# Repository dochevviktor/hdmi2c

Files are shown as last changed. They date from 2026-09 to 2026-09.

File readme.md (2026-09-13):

# HDMI2C Monitor Controller

HDMI2C allows network control (via WiFi) of monitors connected to it via HDMI (via
[DDC]). This allows you to build your own tooling and control systems for your monitors,
rather than relying on awkward inconvient buttons and OSDs. Think of it as an API for
your monitors.

This repository contains the hardware design, made with [KiCAD]. The current
**rev2 XIAO ESP32-C6 carrier is CAD-checked but not physically tested**. Its
[prototype package](hardware/rev2/README.md) includes the BOM, schematic, assembly
drawings, a detailed [3D assembly view](hardware/rev2/assembly-3d-front.png), STEP,
Gerbers, and drills. Open the current project with KiCad 10.

The staged plan for a single-monitor board, XIAO ESP32-C6 migration, and ESPHome
firmware is in [PLAN.md](PLAN.md), including progress and handoff notes for future
sessions. The [upstream BOM and schematic][pages] describe the original revision,
not the current carrier.

## What could you build with this

- A physical brightness knob
- Switch a monitor's input when you wake up your desktop PC or connect your laptop
  to your dock
- IDK probably some other weird shit

## Features

- Seeed Studio XIAO ESP32-C6 with Wi-Fi; soldered castellated mounting
- The XIAO's USB-C power, native programming/logging, regulator, and boot/reset
- One HDMI port (`J7`, HDMI1) with:
  - TPD12S016PWR-based 3.3 V/5 V DDC translation and buffered HPD input
  - Independently controlled DDC enable and protected HDMI 5 V output
- Two small top-actuated buttons and four back-side diagnostic pads
- 42 × 24 mm two-layer carrier with antenna cutout and copper keepouts

Rev2 has 12 fitted components, including the purchased XIAO module, and a 68%
smaller bounding-box area than the 70 × 45 mm single-port rev1. Connector overhangs
are outside those dimensions. There are no mounting holes; provide enclosure
support and cable strain relief.

See the [hardware notes and pin mapping](docs/stage2-hardware.md) for design
decisions, resource provenance, verification, and outstanding physical tests.
ERC/DRC and schematic/PCB parity are clean; 20 design/BOM/preview regression tests pass.
See the [JLCPCB preparation notes](docs/jlcpcb.md) before ordering: factory-specific
settings are applied and all 12 fitted part identities are matched, but final
assembly placement and assembler approval remain pending. J7 is the exact Würth
685119134923 HDMI socket, now matched to JLCPCB **C2930961**.
Historical rev1 findings are recorded in [stage-1 validation](docs/stage1-validation.md).

The updated [review workflow](docs/automation.md) validates rev2 and generates an
interactive BOM/schematic preview using KiCad 10. Pull requests cannot deploy to
Pages. The build was tested locally, including its pinned container; GitHub-hosted
execution and deployment have not been run here.

## JLCPCB submission files

The standard handoff is a ZIP of the [fabrication folder](hardware/rev2/fabrication/)
**including Gerbers, outline and drill files**, plus the clean
[BOM](hardware/rev2/bom-jlcpcb-draft.csv) and a finalized centroid/CPL placement file.
Use the same reviewed revision for all three. The user-managed `bom.csv` is a
matching report, not the clean upload BOM.

The [draft CPL](hardware/rev2/cpl-jlcpcb-draft.csv) puts the raw
[placement CSV](hardware/rev2/positions-front.csv) into JLCPCB's column format, but
U3/J7 still use footprint origins rather than centroids and all rotations are
unverified. Correct those in the online placement preview and confirm XIAO module
handling and soldering the HDMI shell tabs before ordering. See the
[submission checklist](docs/jlcpcb.md#files-to-submit).

## Firmware

Firmware is not included yet. [Stage 3 of the plan](PLAN.md#stage-3--esphome-firmware-over-wi-fi)
will add ESPHome firmware for Wi-Fi control of brightness and input selection,
targeting the XIAO ESP32-C6 carrier from stage 2.

## A word on monitor compatibility

Not all monitors implement DDC that well. Particularly of annoyance, some models I
tested would not listen to DDC commands on inputs that were not active, which, given
this project relies on you having a spare HDMI input which never carries any video, is
kind of a deal breaker.

### Known good monitors

- Dell U2515h — reported working by the original project's author with the
  original hardware/firmware; not yet retested with this XIAO/ESPHome redesign.

## Deferred ideas (outside the current plan)

- A larger carrier option with mounting holes
- Spare ESP32 IO broken out to headers for ease of hacking
- More ambitious, HDMI passthrough to allow use of the project without taking up a whole
  spare HDMI port.

## Is it that useful tho?

You can achieve the same thing without having to build your own hardware with a
Raspberry Pi 4. Support for dual monitor I2C (DDC) was added shortly before I started
this project - guess I didn't check enough :-). This is a much more accessible means to
achieve the same goal. However, if you want a more minimal solution that doesn't require
an entire embedded linux system, this project may be for you.

[DDC]: https://en.wikipedia.org/wiki/Display_Data_Channel
[KiCAD]: https://kicad.org
[pages]: https://wlcx.github.io/hdmi2c

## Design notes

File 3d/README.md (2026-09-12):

# Local 3D models

## XIAO ESP32-C6

`Seeed_Studio_XIAO_ESP32C6.step` is the unmodified STEP supplied by the user in
`seeed-studio-xiao-esp32-c6-1.snapshot.3.zip` on 2026-09-12. It comes from the
[GrabCAD entry](https://grabcad.com/library/seeed-studio-xiao-esp32-c6-1) linked by
[Seeed's resource page](https://wiki.seeedstudio.com/xiao_esp32c6_getting_started/#resources).
The earlier HTTP 403 download limitation is resolved by this local snapshot.

- Original filename: `Seeed Studio XIAO ESP32-C6.step`.
- STEP header timestamp: 2024-11-06T17:15:41+01:00; archive entries: 2024-11-07.
- STEP AP214, millimetres; header identifies Autodesk Translation Framework.
- Assembly label: `Seeed Studio XIAO ESP32-C6 v7`. This is a **CAD model label**,
  not evidence of a hardware V7 revision. It predates the 2026 V1.0 schematic
  used for the carrier's electrical design. Verify the actual purchased module.

SHA-256:

```text
d4d2e3a05c969d69077b256c8b1567805f29be1901635768448c9dc12687c388  supplied ZIP
2e1ce01f4497192485823ca9fffd68e323bafc84cd7b85c2906b5497550be8fc  imported STEP
```

The archive includes front/back reference images but no explicit license or
author attribution file. Retain the source link and verify the applicable terms
before externally redistributing this model or derived assembly exports. The
Seeed schematic/footprint CC BY-SA notice does **not** establish this model's
license. No external publication was performed as part of this integration.

## XIAO placement in KiCad

The library footprint and U3 PCB instance both use
`${KIPRJMOD}/3d/Seeed_Studio_XIAO_ESP32C6.step`, with:

| Setting | X | Y | Z |
| --- | ---: | ---: | ---: |
| Offset, mm | 15.0014 | 8.759341 | 0.25 |
| Scale | 1 | 1 | 1 |
| Rotation, degrees | -90 | 0 | -90 |

The source axes map to footprint 3D axes as `(X,Y,Z) = (source Z, source X,
source Y)` before translation. The source board underside is at Y = -0.25 mm;
the Z offset places it at the mounting plane. It is **not a 0.25 mm standoff**.
The source body is 17.780 × 20.955 × 1.250 mm, close to the official nominal
17.8 × 21 mm outline; it is not scaled to hide this difference. All seven
castellation row centres on both sides align with the carrier's 2.54 mm pitch.
The USB points outward and the ceramic antenna lies over the open notch.

See the [mechanical review](../docs/stage2-hardware.md#detailed-3d-review) and
[rev2 assembly exports](../hardware/rev2/README.md) for clearances, limitations,
and repeatable commands. Other models in this folder predate this integration;
their existing provenance and rights are unchanged.

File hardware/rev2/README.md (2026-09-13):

# Rev2 prototype package

**CAD-checked; not built or electrically tested. Do not treat this as a qualified
production release.** Read the [hardware notes](../../docs/stage2-hardware.md)
before fabrication or assembly. No order or external publication was performed.
JLCPCB preparation is documented in [JLCPCB notes](../../docs/jlcpcb.md).
**J7 is now matched to C2930961; final placement and assembler approval remain pending.**

- [Schematic PDF](schematic.pdf)
- [Engineering BOM](bom-design.csv): 12 fitted components, including the XIAO,
  with reviewed specifications and purchasing fields.
- [JLCPCB matching CSV](bom.csv): user-managed snapshot with J7 explicitly
  corrected to C2930961. Other rows are preserved; this is not the clean upload BOM.
- [JLCPCB draft BOM](bom-jlcpcb-draft.csv) and [BOM audit](checks/jlcpcb-bom.json):
  seven matched part groups / 12 components; J7 is the existing Würth socket,
  685119134923 / C2930961. Still a draft pending assembly review, not a release.
- [Front assembly](assembly-front.svg) and [back assembly](assembly-back.svg):
  enlarged 4:1 drawings; the back view is mirrored. All fitted parts are front-side;
  the four back test pads are not fitted components.
- [1:1 fit-check PDF](fit-check-1to1.pdf): print at 100%, with page fitting disabled.
  Confirm the carrier measures 42 × 24 mm before comparing actual parts.
- [Front copper](copper-front.svg) and [back copper](copper-back.svg).
- [3D front view](assembly-3d-front.png), [3D back view](assembly-3d-back.png), and
  [assembly STEP](assembly.step): include the detailed XIAO and all 12 fitted parts.
  Nominal envelope is about 43.90 × 25.51 × 8.38 mm, excluding cables and solder.
  The supplied XIAO model is from 2024; check the actual module revision and the
  [model provenance/redistribution caveat](../../3d/README.md) before reuse.
- [Placement data](positions-front.csv): mm, absolute KiCad origin, standard
  KiCad rotations. **U3's footprint origin is not its body centroid**; the assembler
  must check its machine origin and rotation. This is not a finalized JLCPCB CPL;
  U3 and J7 require offset/rotation review. J7 is mixed SMT/plated-slot assembly
  and is included in this file, not omitted as a non-SMD part.
- [JLCPCB draft CPL](cpl-jlcpcb-draft.csv) and [CPL report](checks/jlcpcb-cpl.json):
  those 12 placements in JLCPCB's `Designator,Mid X,Mid Y,Layer,Rotation` format.
  XY and rotations are unchanged, so U3/J7 still need centroid corrections and all
  rotations need placement-preview review.
- [Fabrication files](fabrication/): two copper layers, both solder masks and
  silkscreens, paste, outline, plated/non-plated Excellon drills, and drill maps.
  There are 33 plated 0.3 mm vias and four plated 0.9 mm-wide routed HDMI shell
  slots. The separate NPTH drill file and back-paste layer are intentionally empty.
- [ERC report](checks/erc.json), [DRC/parity report](checks/drc.json),
  [netlist](checks/netlist.xml), [source hashes](checks/source-sha256.txt), and
  [nominal 3D clearance report](checks/mechanical-3d.json). The latter records
  source and STEP hashes; it is not evidence of a physical fit or RF test.

Fabrication assumptions: 2 layers, 1.6 mm FR-4, nominal 35 µm (1 oz) copper, green mask;
0.20 mm minimum tracks/clearance, 0.60/0.30 mm vias, 0.30 mm copper-to-edge
clearance, 0.12 mm mask web, and 1.0/0.15 mm minimum silk text height/stroke.
Confirm these, mask web capability, routed plated slots, and stencil
handling of the XIAO with the fabricator. The 42 × 24 mm measurement excludes
connector overhangs. There are no mounting holes; provide enclosure support.

Regenerate from the project root with KiCad 10 and its standard symbol, footprint,
and 3D-model libraries plus the `pcbnew` Python module:

```sh
bash scripts/export_rev2.sh
sha256sum -c hardware/rev2/checks/source-sha256.txt
```

The export script runs ERC, DRC/parity, the electrical/mechanical/model contract
check, and 20 regression tests before exporting production-format files. It never
overwrites `bom.csv`. Every purchasing identity/footprint mismatch stops the export;
all 12 identities now match. If the export
fails, do not use earlier output files as a release for the newly edited design.
The updated [review workflow](../../docs/automation.md) shares that validation
gate and generates a separate 2D preview; it does not publish this whole package.
Its build was tested locally in the pinned KiCad container. Actual GitHub-hosted
execution and Pages deployment have not been run here.

For JLCPCB, the normal handoff is a ZIP of `fabrication/` **including drills**,
the clean BOM, and a finalized centroid/CPL. See the [submission checklist](../../docs/jlcpcb.md#files-to-submit).
Do not submit `positions-front.csv` or the unmodified draft CPL as an approved CPL:
custom-part offsets/rotations and JLCPCB's placement preview still need review.

### Repeat the solid-clearance review

This optional audit uses OpenCascade, separately from the KiCad checks above.
After exporting, refresh its report in an isolated environment (verified here
with Python 3.14 and the pinned dependency):

```sh
cad_review_dir="$(mktemp -d -t hdmi2c-3d.XXXXXX)"
python3 -m venv "$cad_review_dir/venv"
"$cad_review_dir/venv/bin/pip" install -r scripts/requirements-3d.txt
"$cad_review_dir/venv/bin/python" scripts/check_rev2_3d.py hardware/rev2/assembly.step \
  --output hardware/rev2/checks/mechanical-3d.json
```

Reuse that environment for subsequent audits. The script checks XIAO-to-substrate
and XIAO-to-other-part solid intersections/distances, HDMI shell-to-substrate
interference, and the antenna's projection onto the carrier. It requires models
for all fitted parts and a current source manifest. It does not check solder,
cable plugs, enclosure, tolerances, or RF. Re-exporting the STEP changes its hash;
rerun this audit before citing an older report as current.

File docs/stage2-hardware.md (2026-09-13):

# Stage 2 — XIAO ESP32-C6 carrier (rev2)

Design date: 2026-09-12. This is a prototype design, not tested hardware.
See [PLAN.md](../PLAN.md) for project status and the remaining bring-up work.
The ESPHome implementation is still stage 3; no working firmware is implied.
For the current factory settings, selected purchasing codes, and unresolved
connector/assembly decisions, see [JLCPCB preparation](jlcpcb.md).

## What changed

The complete Seeed Studio XIAO ESP32-C6 replaces the bare WROOM module. Its
USB-C socket, native USB programming, regulator, RF circuit, and boot/reset
buttons replace the carrier's USB socket, CP2102N, regulator, programming
transistors, and reset circuit. There is no battery connection on this carrier.

The single HDMI connector remains `J7`, Würth **685119134923**. The old discrete
DDC level shifters, HPD divider, jumpers, and HDMI supply circuit are replaced by
`U4`, **TPD12S016PWR**, in the solderable **PW/TSSOP-24** package. This is not the
pin-compatible UQFN version. The old nominal 5 V LDO is no longer in the USB-to-HDMI
path, avoiding its input-headroom problem. Component references reused across
revisions do not imply interchangeable parts; use the rev2 BOM and schematic.

The carrier has a **42 × 24 mm bounding box**, versus 70 × 45 mm in stage 1:
68% less bounding-box area. The antenna notch removes additional material.
There are **12 fitted components**, plus four etched test pads (16 footprints).
The XIAO counts as one purchased assembly; its onboard parts are not counted
individually. Mounting holes are omitted. Two smaller, top-actuated
Omron B3U-1000P buttons replace the original forward-facing switches.

## Pin and power contract for firmware

The table uses **physical XIAO castellation numbers**, not ESP32 chip pad numbers.
KiCad's local net names acquire a leading `/` in the netlist.

| Function / net | Old WROOM GPIO | XIAO label | ESP32-C6 GPIO | U3 pad | Other endpoint |
| --- | --- | --- | --- | --- | --- |
| `I2C_SDA` | 27 | D4 | 22 | 5 | U4.3 SDA_A |
| `I2C_SCL` | 26 | D5 | 23 | 6 | U4.2 SCL_A |
| `HDMI_5V_EN`, active high | 18 | D0 | 0 | 1 | U4.12 CT_HPD |
| `DDC_EN`, active high | New | D1 | 1 | 2 | U4.5 LS_OE |
| `HDMI_HPD`, input | 16 | D2 | 2 | 3 | U4.4 HPD_A |
| `BUTTON1`, active low | 13 | D8 | 19 | 9 | SW2.1 |
| `BUTTON2`, active low | 14 | D9 | 20 | 10 | SW3.1 |
| `+3V3`, regulator output | — | 3V3 | — | 12 | U4.24 VCCA; button pull-ups |
| `GND` | — | GND | — | 13 | Common carrier/HDMI ground |
| `VBUS`, USB 5 V | — | 5V | — | 14 | U4.11 VCC5V |

Unused castellations 4, 7, 8, and 11 are intentionally unconnected. No carrier
signal uses the C6 strapping GPIOs 4, 5, 8, 9, or 15, or its native USB GPIO12/13.
The module retains its own boot/reset buttons. Mapping was checked against Seeed's
schematic/pinout and the [Espressif datasheet, v1.5](https://www.espressif.com/sites/default/files/documentation/esp32-c6_datasheet_en.pdf).

Reserve internal **GPIO3** for RF-switch enable (low) and **GPIO14** for antenna
selection (low for onboard ceramic, high for external). These are not carrier
I/O. Stage 3 must initialize them using the selected framework's XIAO support or
explicit startup configuration. See [Seeed's RF-switch instructions](https://wiki.seeedstudio.com/xiao_esp32c6_getting_started/#hardware-overview).

Suggested startup sequence for stage 3:

1. Set `HDMI_5V_EN` and `DDC_EN` low before configuring monitor control.
2. Initialize the XIAO antenna selection and Wi-Fi; configure HPD as an input.
3. Assert `HDMI_5V_EN`, then allow a conservative 10 ms initial settling interval.
   This is a proposed firmware margin, not a measured monitor-ready time.
4. Assert `DDC_EN`; start DDC at 100 kHz with open-drain signaling and bounded
   timeouts. Verify clock stretching, signal levels, and transaction timing on
   hardware before relying on communication.
5. To turn the HDMI interface off, disable DDC first, then remove HDMI 5 V.

Never intentionally leave LS_OE high with CT_HPD low: TI marks that state invalid.
HPD is advisory for this application; do not assume an inactive monitor input
must report HPD before trying DDC. Monitor readiness and retry timing need actual
monitor tests. The new `DDC_EN` output is mandatory, not interchangeable with the
old single-enable firmware wiring. R24/R25 are 100 kΩ pulldowns; R26/R27 are
10 kΩ button pull-ups. Both buttons short their signals to ground when pressed.

## HDMI electrical interface

| J7 pin | Signal | U4 PW pin / connection |
| --- | --- | --- |
| 15 | SCL, 5 V side | 8 SCL_B |
| 16 | SDA, 5 V side | 9 SDA_B |
| 17 | DDC ground | Common GND |
| 18 | Switched HDMI 5 V | 13 5V_OUT |
| 19 | HPD, 5 V side | 10 HPD_B |
| 2, 5, 8, 11, SH | Pair shields / shell | Common GND |

U4 ground pins **6, 14, and 19** all connect to ground. Unused CEC pins 1/7 and
TMDS clamp pins 15/16/17/18/20/21/22/23 are intentionally unconnected; this board
does not send video. C1/C2/C3 are 100 nF bypass capacitors on VCC5V, VCCA, and
5V_OUT respectively, with short local connections and nearby ground vias.

The [TI datasheet, SLLSE96F, October 2015](https://www.ti.com/lit/ds/symlink/tpd12s016.pdf)
specifies integrated DDC pull-ups (10 kΩ to VCCA; 1.75 kΩ to 5V_OUT), level
translation, HPD buffering, and connector-side protection. Do not fit extra DDC
pull-ups by default. The HDMI supply supports a 55 mA load; short-circuit limiting
is 150 mA typical (100–200 mA), **not a precise 55 mA cutoff**. Output drop is
50 mV maximum at 55 mA under the stated test conditions. Reverse-current blocking
is specified on 5V_OUT and the cable-side DDC/CEC pins when powered down. These
component specifications do not establish board-level ESD or HDMI certification.

USB supplies both the XIAO and HDMI load. Do not inject a second supply into
U3.14/TP1 or connect a battery for this revision. Test cable/supply voltage drop
and Wi-Fi transients. The buffered DDC interface has an A-side low-level offset;
bench-check logic-low margins and avoid cascading another offset-type bus buffer
without an electrical review. Keep the HDMI cable disconnected for initial
power-up and solder inspection.

## Mechanical and assembly review

- Two copper layers, nominal 1.6 mm FR-4. The board outline has 1 mm radii and an
  open antenna notch. Copper clearance to the outline is 0.3 mm minimum.
- U3 is soldered by its 14 side castellations, with USB at the carrier's upper
  edge. Its PCB body is nominally 21 × 17.8 mm. The USB socket projects beyond the
  carrier outline; 42 × 24 mm describes the carrier, **not the assembled envelope**.
- The local XIAO footprint preserves Seeed's side-pad coordinates, size, and
  numbering. Underside debug/test/battery lands 15–24 were deliberately removed.
  The interior beneath the module prohibits front copper, pads, and vias so
  exposed underside module contacts cannot touch carrier conductors.
- The antenna is over the notch at the opposite end from USB. A separate rule
  area prohibits copper, traces, vias, and pads on **both copper layers**. Keep
  an enclosure, metal fasteners, and cables away from this end; RF performance
  and enclosure clearance are not validated by DRC.
- The XIAO top-side boot/reset buttons and external antenna socket remain
  accessible. Side solder fillets remain reachable. Assemble the low components
  first, inspect for bridges, then fit the module/HDMI socket as appropriate to
  the assembly process. Verify a 1:1 print against actual parts before ordering.
- J7 faces the right edge. Its original SMT and plated-slot land geometry is
  retained, reviewed against the [Würth drawing, rev. 001.002](https://www.we-online.com/components/products/datasheet/685119134923.pdf).
  The body/courtyard and local STEP transform are included. Through-hole shell
  tabs require solder; an SMT-only assembly operation is insufficient.
- There are no screw holes. Provide nonconductive enclosure support and cable
  strain relief; do not treat the castellated joints as cable-load supports.
- All fitted parts are on the front. TP1–TP4 are **back-side** exposed pads:
  HDMI 5 V, GND, SCL, SDA. Back assembly plots are mirrored for a bottom view.
- The user supplied Seeed's linked GrabCAD STEP snapshot after the original
  download returned HTTP 403. It is now linked in both the local XIAO footprint
  and U3 PCB instance. Nominal 3D checks are below; physical fit is still pending.

### Detailed 3D review

Reviewed on 2026-09-12 using KiCad 10.0.6 STEP exports/renders and OpenCascade
(`cadquery-ocp 8.0.1.0.0`). All 12 fitted components have models; test pads do not
need separate models. The XIAO STEP is a **2024 mechanical snapshot**, not proof
of the exact purchased module revision. See [model provenance and transform](../3d/README.md).
The 3D integration itself changed neither electrical design, routing, lands,
outline, nor BOM. The subsequent JLCPCB follow-up updates purchasing metadata
and silkscreen, as documented separately.

| Nominal CAD check | Result |
| --- | --- |
| XIAO castellation rows | All 14 align to the footprint's seven 2.54 mm-pitch rows |
| XIAO versus other fitted parts | No solid overlap; nearest is R24 at 1.82 mm; U4 at 2.82 mm |
| XIAO / carrier substrate | No solid overlap; flat modeled underside at the mounting plane |
| HDMI shell / carrier substrate | No solid overlap; tabs pass through the plated slots |
| USB overhang beyond the carrier's upper edge | 1.512 mm; plug and strain relief not modeled |
| Ceramic antenna projection / carrier material | Over the notch; minimum planar edge distance approximately 0.294 mm |
| Overall modeled assembly envelope | Approximately 43.90 × 25.51 × 8.38 mm, including connector overhangs and shell tabs |

The small antenna-to-notch edge distance is **not an RF clearance recommendation**.
The existing all-layer copper keepout remains unchanged, but a successful geometric
check does not establish reception, detuning, or enclosure/cable clearance.
Verify Wi-Fi with physical parts and revise the keepout/notch if tests require it.

The model's Z offset corrects its source origin; it does not add a solder standoff.
The STEP export's 0.085 mm module-to-FR4 separation reflects the nominal mounting
plane versus substrate geometry, which excludes copper/mask; it is not an assembly
gap specification. Tolerances, solder, internal XIAO part interference, mating
USB/HDMI plugs, enclosure, cable loads, and RF behavior are outside this audit.
Confirm the older model against an actual XIAO before designing a close-fitting case.

[Front](../hardware/rev2/assembly-3d-front.png) and
[back](../hardware/rev2/assembly-3d-back.png) views,
[assembly STEP](../hardware/rev2/assembly.step), and the
[hashed solid-check report](../hardware/rev2/checks/mechanical-3d.json) are included.

## Resource provenance

Resources were retrieved on 2026-09-12 from the [Seeed resource list](https://wiki.seeedstudio.com/xiao_esp32c6_getting_started/#resources).

| Resource | Version / use |
| --- | --- |
| [XIAO schematic PDF](https://files.seeedstudio.com/wiki/SeeedStudio-XIAO-ESP32C6/XIAO_ESP32_C6_v1.0_SCH_260114.pdf) | V1.0, title dated 2026-01-14; power, pinout, RF, controls |
| [XIAO KiCad project](https://files.seeedstudio.com/wiki/SeeedStudio-XIAO-ESP32C6/XIAO_ESP32_C6_v1.0_SCH&PCB_260114.zip) | Archive named 260114; PCB entry dated 2025-02-11, schematic entries January 2026; layout/mechanics cross-check |
| [XIAO footprints](https://files.seeedstudio.com/wiki/XIAO-KiCad-Library/New_XIAO_Series_Footprints.zip) | `XIAO-ESP32-C6-SMD.kicad_mod`, entry dated 2026-01-05; adapted as `hdmi2c:XIAO_ESP32C6_Castellated` |
| [XIAO symbols](https://files.seeedstudio.com/wiki/XIAO-KiCad-Library/XIAO_Series_SCH_Symbols.zip) | Used as a pinout reference; local symbol describes the 14 connected castellations and power direction |
| [Pinout workbook](https://files.seeedstudio.com/wiki/SeeedStudio-XIAO-ESP32C6/res/XIAO_ESP32C6_Pinout.xlsx) | Cross-check of GPIO labels |
| [XIAO 3D model](https://grabcad.com/library/seeed-studio-xiao-esp32-c6-1) | User-supplied snapshot.3 ZIP; STEP dated 2024-11-06, imported unchanged; [hashes and placement](../3d/README.md) |
| [Omron B3U datasheet](https://omronfs.omron.com/en_US/ecb/products/pdf/en-b3u.pdf) | B3U-1000P, non-illuminated top-actuated switch |

Downloaded Seeed source hashes (SHA-256):

```text
510f3f917bcded1201ca5c63374409183457c1ef83a836988517d6802180dad7  schematic PDF
cea2ed66da575e4a1dd6c7a9acd60583ed4a9adbf6b1d2952851c1e4199c05fc  KiCad project ZIP
36f7e87db783002f20dad0fb36136c877dbc49e051293997993a988cac065698  footprint ZIP
9a423cc0683f3f6a2716a47f817556bfe0bc1a9720041712cad36902a0c25fe5  symbol ZIP
e2dae530c359e66ba704039f86cfea4bc316596fde367d992723509777746494  pinout XLSX
```

Attribution: XIAO design and source library by Seeed Studio; the source schematic
credits Linus.Liao and carries CC BY-SA 4.0. The adapted XIAO footprint preserves
that attribution and is provided under [CC BY-SA 4.0](https://creativecommons.org/licenses/by-sa/4.0/).
Adaptations cover the carrier mounting lands, fabrication graphics, courtyard,
name, description, and the linked 3D model's placement. This notice does not
relicense the linked GrabCAD STEP, unrelated original HDMI2C assets, or third-party
KiCad libraries; the STEP archive has no explicit license file.

## Physical bring-up — not performed

- [ ] Inspect part orientation, castellations, TSSOP solder bridges, and HDMI slots.
- [ ] Verify unpowered resistance between each supply rail and ground.
- [ ] With HDMI disconnected, power from a current-limited USB supply and check
  VBUS/3V3, reset-off enables, temperature, and absence of unexpected HDMI 5 V.
- [ ] Verify USB enumeration, native flashing/logging, boot/reset, and both buttons.
- [ ] Exercise enables; check HDMI 5 V under load and disabled/powered-off backfeed
  behavior with controlled equipment, without using a monitor as a fault fixture.
- [ ] Verify Wi-Fi reception with the intended antenna, USB/HDMI cables, enclosure,
  and worst-case transmit activity; check supply dips and resets.
- [ ] Check DDC idle/low levels, rise times, clock stretching, HPD, and enable order.
- [ ] Test a monitor's active and inactive HDMI inputs, sleep/wake and cable reconnect.
- [ ] Complete stage-3 firmware tests before claiming brightness/input control works.

## CAD verification and handoff

Checked with **KiCad CLI / pcbnew 10.0.6** on 2026-09-12. The schematic was redrawn
in format 20250114; the new PCB uses format 20260206. Use KiCad 10 for this revision.
This intentionally supersedes stage 1's legacy-format preservation. Existing
unrelated project preferences were preserved; minimum clearance, copper-to-edge,
and silkscreen spacing are now 0.20, 0.30, and 0.15 mm respectively after the
JLCPCB profile update. There are no
DRC exclusions. Stage 1's 7 ERC and 10 DRC errors no longer apply to this redesign.
Results use the project's configured severities. Six inherited checks remain
ignored (missing courtyard, track endpoint centered on via, tuning-profile
geometry, footprint filters, and PTH/NPTH inside courtyard); the JSON report
lists them explicitly. No rules were disabled to obtain the rev2 result.

| Check | Result |
| --- | --- |
| ERC, including warnings | 0 findings |
| DRC, all-track errors, including warnings | 0 findings |
| Unrouted connections | 0 |
| KiCad schematic/PCB parity | 0 findings |
| Independent electrical-contract / netlist comparison | 38 matching pin groups, including 24 intentional NC groups |
| XIAO footprint comparison to downloaded Seeed library | All 14 side-pad positions, sizes, and numbers match |
| PCB outline | 42 × 24 mm; approximately 915.64 mm² material area |
| Regression tests | 20 pass: 10 design, 8 BOM parser/identity, and 2 preview-output safety checks |
| XIAO model contract | Pinned STEP hash and identical reviewed transforms in library and PCB |
| Nominal 3D checks | XIAO/carrier/component clearances, antenna projection, HDMI shell/slot clearance; details above |
| Visual review | Schematic, front/back assembly and copper, plated-slot drill output, detailed front/back 3D views |
| Physical, RF, USB/programming, monitor, and ESD tests | Not performed |

The routing was assisted locally by Freerouting 2.4.1, with manual local bypass
connections and ground-return vias, followed by KiCad clearance corrections and
zone refill. KiCad DRC is the final CAD acceptance check, not the router's score.
There are 221 track segments and 33 vias. No fabrication order was placed.

The [prototype package](../hardware/rev2/README.md) contains the BOM, placements,
assembly drawings/STEP/renders, schematic PDF, Gerbers, drills, and reports.
Run `bash scripts/export_rev2.sh` after edits; it stops on failed CAD/contract tests.
The package README also gives the separate optional OpenCascade command to refresh
the solid-check report. Its source/STEP hashes identify the assembly actually checked.
`python3 -m unittest discover -s tests -v` exercises swapped SDA/SCL, a direct
5 V-to-GPIO miswire, changed land geometry, missing/weakened antenna keepouts,
and missing/rotated/vertically misplaced XIAO models.
The JLCPCB follow-up also checks minimum silk graphic width and protects against
ambiguous matching columns, missing parts, and the wrong HDMI IC auto-match.
These are design-regression checks, not circuit simulation or evidence that DDC
works on a monitor.

Next: use the 1:1 fit print and physical bring-up checklist before trusting a
prototype. Stage 3 can begin its ESPHome component/configuration work against the
pin contract above when requested, without marking the physical stage-2 milestone
complete. Compare this older XIAO model with a sample before enclosure design.

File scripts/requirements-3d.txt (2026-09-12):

# Optional solid-clearance audit; not needed for KiCad exports or electrical checks.
cadquery-ocp==8.0.1.0.0

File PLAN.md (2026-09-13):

# HDMI2C development plan

This is the handoff document for continuing work across sessions. Read it together
with `readme.md`, inspect the working tree, and update the checkboxes and session
notes after each meaningful change. Do not assume a checked design task has been
tested on physical hardware.

## Intended result

A small, inexpensive controller for one monitor, connected to a spare HDMI input
and controlled over Wi-Fi using ESPHome. Initial controls are brightness and input
selection through DDC/CI over I2C. The final MCU board is a Seeed Studio XIAO
ESP32-C6. USB supplies power; the HDMI connection does not carry video.

The stages below are sequential. Stage 1 is complete in CAD. The current
implementation request is stage 2; stage 3 is the planned firmware follow-up.
Stage 2 is now complete in CAD as `rev2`; its physical bring-up is still pending.

## Stage 1 — one HDMI port

Keep the ESP32-WROOM-32 and HDMI1 (`J7`) to isolate this change from the MCU redesign.
Keep existing reference designators so diffs and earlier assembly information
remain easy to follow.

- [x] Inspect the schematic, PCB, libraries, README, and existing local changes.
- [x] Identify the complete HDMI2 circuit to remove:
  - connector `J8`;
  - shield and I2C jumpers `JP2`, `JP7`, `JP8`;
  - level shifters `Q4`, `Q6` and pull-ups `R8`, `R10`, `R12`, `R14`;
  - HPD divider `R20`, `R21`;
  - switchable 5 V supply `U5`, `Q8`, `C6`.
- [x] Capture baseline ERC/DRC results before editing.
- [x] Remove these symbols, their wires, labels, junctions, and cached instances.
  Mark the four freed MCU pins intentionally unconnected.
- [x] Remove matching footprints, HDMI2 nets, traces, and obsolete shared-supply
  branches from the PCB. Preserve the complete HDMI1 circuit.
- [x] Reduce the board outline, reposition affected mounting holes/artwork, and
  refill copper. Record the resulting dimensions and component-count reduction.
- [x] Verify schematic/PCB connectivity, ERC, DRC, and visual exports. Record
  inherited findings separately from regressions; resolve new electrical or
  mechanical errors introduced by this change.
- [x] Update README and record a stage-1 handoff here. Generated manufacturing
  files should only be treated as release files after the outstanding checks pass.

Acceptance: exactly one HDMI connector in schematic and PCB, no HDMI2 circuitry
or routing, HDMI1 pin connectivity preserved, a smaller board, and explicit
verification results. A physical build is a separate validation milestone.

## Stage 2 — XIAO ESP32-C6 carrier

- [x] Read Seeed's schematic, pinout, dimensions, and CAD resources; record the
  exact module revision and resource versions used. The documented module size
  is 21 × 17.8 mm. This is a carrier redesign, not a pin-compatible WROOM swap.
- [x] Add/verify a local symbol and footprint for the complete XIAO board,
  including pad numbering, mounting method, USB clearance, antenna clearance,
  and access to boot/reset. Prefer soldered castellated pads for compactness;
  check assembly access before fixing the layout.
- [x] Create an explicit old-to-new signal mapping. Start with XIAO `D4/GPIO22`
  for SDA and `D5/GPIO23` for SCL; select remaining exposed GPIOs for HDMI 5 V
  enable, HPD input, and any retained buttons after checking boot constraints.
  Reserve the board's antenna-control GPIOs according to Seeed's documentation.
- [x] Use the XIAO's USB-C power/programming connection and onboard regulation.
  Remove the redundant WROOM, USB connector, USB-UART bridge, auto-programming
  circuit, and associated parts once their replacement paths are confirmed.
- [x] Review the HDMI electrical interface: 3.3 V/5 V level shifting, pull-ups,
  HPD divider, common ground/shield, ESD, enable defaults, and backfeed behavior.
  Audit the inherited 5 V LDO/pass-FET circuit with USB input voltage and dropout
  in mind before deciding to retain or replace it. Do not wire 5 V DDC directly
  to an ESP32 GPIO.
- [x] Redraw and compact the carrier PCB around one HDMI connector and the XIAO.
  Revisit buttons and mounting holes only as needed for the smaller layout.
- [x] Run ERC, DRC, schematic/PCB parity, and a datasheet/2D footprint/connector
  review. Generate a BOM, assembly view, schematic PDF, Gerbers, and drills for
  the reviewed revision.
- [x] Integrate the user-supplied detailed XIAO STEP model; align it in the library
  and PCB, review nominal solid clearances, and export assembly STEP/front/back
  views. Record model provenance, transform, and repeatable checks.
- [ ] Verify the 1:1 land print against physical samples and assembled/enclosure
  clearances. Compare the 2024 model snapshot with the actual purchased module;
  cable plugs, solder, tolerances, and RF behavior remain unverified.
- [x] Review the supplied JLCPCB template and matching BOM; apply appropriate
  KiCad 10 factory limits, update silk, preserve the raw matching CSV, and save
  reviewed purchasing fields with a guarded draft export.
- [x] Update the review workflow for KiCad 10, share local/CI validation, retain
  the interactive BOM preview, and prevent pull-request Pages deployments.
  Verify the build locally in its pinned container; no remote run/publication.
- [x] Confirm J7's exact catalog identity: Würth 685119134923 / C2930961; update
  purchasing fields/BOM without a footprint substitution. All 12 identities match.
- [ ] Complete JLCPCB assembly preparation: confirm current availability, complete
  XIAO reflow/handling and HDMI shell-tab soldering, choose service/tooling/panel
  needs, and verify the final CPL offsets/rotations and placement preview.
- [ ] Bring up hardware: check USB, 3.3 V and HDMI 5 V rails, boot/programming,
  Wi-Fi reception, DDC idle levels and waveforms, and HPD/enable behavior.

Acceptance: documented XIAO pin mapping, compact carrier, resolved release-blocking
CAD findings, successful power/programming/Wi-Fi bring-up, and an electrically
verified DDC connection. Record any checks that require a physical board.

## Stage 3 — ESPHome firmware over Wi-Fi

- [ ] Review the three reference projects below at recorded commits; inspect
  their actual DDC implementations and licenses before reusing code. MoniBee
  uses the ESP32-C6 with Zigbee and is a protocol reference, not the requested
  Wi-Fi/ESPHome implementation. Distinguish DDC/CI on HDMI SDA/SCL from CEC.
- [ ] Pin a supported ESPHome version and compile a minimal XIAO configuration
  using `variant: esp32c6` and the ESP-IDF framework. Confirm flash size, USB
  logging, antenna configuration, Wi-Fi, encrypted native API, and OTA. Keep
  credentials in an untracked `secrets.yaml` with a checked-in example.
- [ ] Implement a reusable local ESPHome external component for DDC/CI. Plan
  for a configurable I2C bus/address, checksums, response validation, explicit
  transaction timing, serialized requests, bounded retries, and offline recovery.
  Verify address notation (7-bit address versus shifted wire address) against
  the source implementations. Avoid an always-running I2C scan on the DDC bus.
- [ ] Add a brightness `number` entity and input-source `select` entity. Support
  monitor-specific source codes; confirm readback and brightness scaling against
  the monitor's reported range. Identify unsupported controls without blocking
  Wi-Fi/API operation. Add power control later if supported and useful.
- [ ] Add hardware pin substitutions, conservative polling, availability/error
  reporting, safe startup behavior, and optional button actions. Keep the bus
  state machine nonblocking so network and watchdog tasks continue to run.
- [ ] Verify framing/checksum/error handling with meaningful protocol tests and
  captured/known transactions; run ESPHome config validation and compilation.
- [ ] Test on a real monitor with DDC/CI enabled: brightness set/read, input
  switch/read, inactive spare HDMI input, cable reconnect, monitor sleep/wake,
  power loss, controller reboot, Wi-Fi loss/recovery, and OTA.
- [ ] Document flashing, ESPHome/Home Assistant setup, supported monitor models
  and settings, troubleshooting, and the exact tested hardware/firmware versions.

Acceptance: an ESPHome build for this board exposing working brightness and input
controls over Wi-Fi, with readback/error handling and recorded monitor tests.

## Constraints and decisions to carry forward

- Some monitors ignore DDC on inactive inputs. Test the actual target monitor
  early; firmware cannot guarantee support on an arbitrary spare HDMI port.
- Keep the monitor's normal video connection separate. HDMI passthrough, dual
  monitors on one carrier, Zigbee/Matter, and ambient-light/IR features are outside
  the current scope.
- Stage 1 kept the existing power architecture and GPIO mapping. Stage 2 replaces
  these with the XIAO and TPD12S016PWR; use the new firmware pin contract in
  [stage-2 hardware notes](docs/stage2-hardware.md), including the new DDC enable.
- Preserve user changes. At the start of this work, `hdmi2c.kicad_pro` already had
  KiCad version/settings changes, and `.history/` and `.idea/` were untracked.
- Stage 1 retained schematic 20211123 / PCB 20211014. The stage-2 redraw uses
  schematic 20250114 / PCB 20260206, verified with KiCad 10.0.6. Use KiCad 10 for
  the new carrier. The rev1 files remain available in Git history.

## References

Reviewed for planning on 2026-09-12; recheck versions before implementing firmware.

- [Seeed XIAO ESP32-C6 pinout and resources](https://wiki.seeedstudio.com/xiao_esp32c6_getting_started/#resources)
  — module dimensions, GPIO mapping, power and antenna controls.
- [fluxfur/ddcBrightness](https://github.com/fluxfur/ddcBrightness)
  — existing HDMI monitor-control implementation to inspect for DDC behavior.
- [TeaRex-coder/hardwareddc firmware](https://github.com/TeaRex-coder/hardwareddc/tree/main/firmware)
  — ESP32 firmware; its [README](https://github.com/TeaRex-coder/hardwareddc)
  describes control through a spare HDMI input and links the DDC/VCP library.
- [ItsEcholot/MoniBee](https://github.com/ItsEcholot/MoniBee)
  — ESP32-C6 monitor control; inspect source rather than relying on its mixed
  CEC/DDC terminology. Its board is a C6 Supermini, not the XIAO.
- [ESPHome ESP32 platform](https://esphome.io/components/esp32/)
  — C6 variant and ESP-IDF support.
- [ESPHome external components](https://esphome.io/components/external_components/)
  — component integration approach to check during stage 3.

## Session handoff

### 2026-09-12 — plan and stage 1

Status: stage 1 complete in CAD; hardware validation remains outstanding.

- No firmware existed in this repository at the start of this work.
- Board outline reduced from 95 × 45 mm to 70 × 45 mm (26.3% less area). Removed
  15 circuit components; 46 PCB footprints remain including holes and artwork.
- HDMI1 (`J7`) is preserved, including its original GPIO26 SCL, GPIO27 SDA,
  GPIO16 HPD, and GPIO18 5 V enable mapping. Removed HDMI2 from both CAD files.
- Updated the local logo footprint and its PCB instance to fit the smaller board
  and identify it as `rev1`. The user-edited project settings were left intact.
- Verification: 88 matching pin groups, no unrouted connections, and no new ERC,
  DRC, or schematic/PCB parity findings compared with the baseline. Inherited
  findings remain (7 ERC errors and 10 DRC errors); this is not a fabrication
  release. See [stage-1 verification](docs/stage1-validation.md) for counts,
  retained pin mapping, limitations, and commands.
- Added `scripts/check_connectivity.py` for repeatable schematic/PCB pin-group
  comparison and optional comparison with an earlier netlist.
- Next implementation task: stage 2, starting with the official XIAO schematic,
  mechanical footprint, and explicit pin/power mapping. Review the inherited
  HDMI supply circuit and CAD findings as part of that redesign. Do not begin
  the ESPHome implementation with the old WROOM pin mapping.

### 2026-09-12 — stage 2 XIAO carrier

Status: **CAD complete; physical stage-2 acceptance not yet achieved.** Stage 3
firmware remains unimplemented. Baseline at this session's start: `af1aed1`.

- U3 is the complete XIAO ESP32-C6 V1.0, using Seeed's January 2026 schematic and
  reviewed 14 castellation lands. Resource links, hashes, and attribution are in
  [stage-2 hardware notes](docs/stage2-hardware.md).
- Replaced the WROOM support circuits and discrete HDMI interface with a
  USB-powered XIAO plus TPD12S016PWR. DDC remains properly level translated;
  CT_HPD and LS_OE have independent GPIOs and reset-off pulldowns. HDMI shell and
  signal grounds are now directly common. No external battery supply is used.
- Board is 42 × 24 mm (68% smaller bounding-box area than stage 1), with antenna
  cutout and copper keepouts. 12 fitted components / 16 footprints, including
  two smaller top-actuated buttons and four back-side test pads. No screw holes.
- Pin contract: GPIO22 SDA, GPIO23 SCL, GPIO0 HDMI 5 V enable, GPIO1 DDC enable,
  GPIO2 HPD, GPIO19/20 buttons. Reserve GPIO3/14 for the XIAO antenna controls.
  Enable HDMI 5 V before DDC; disable DDC before removing HDMI 5 V.
- Verification: 0 ERC, 0 DRC, 0 unrouted, 0 parity findings; 38 matching pin
  groups; all 14 lands compared against Seeed; six regression tests pass.
  No exclusions were introduced. All CAD issues inherited from rev1 are gone.
- Generated [rev2 prototype package](hardware/rev2/README.md), including BOM,
  assembly views, 1:1 fit print, schematic PDF, Gerbers, drills, and reports.
  Reproduce with `bash scripts/export_rev2.sh`; it gates exports on checks/tests.
- Unrelated user changes in `.history` were preserved. Existing upstream Pages
  automation was not upgraded or run. No order, push, or commit was made.
- Next physical action: verify actual parts against the fit print, then perform
  the power/USB/RF/DDC bring-up checklist. Detailed XIAO 3D fit remains pending.
  Next software action, when requested: start stage 3 against the rev2 pin contract,
  review reference project commits/licenses, then pin and compile ESPHome/C6.

### 2026-09-12 — detailed XIAO 3D model follow-up

Status: **nominal 3D review complete; physical stage-2 acceptance still pending.**
Baseline: `59bcef6`. The user supplied the previously inaccessible GrabCAD ZIP.

- Imported its STEP unchanged as `3d/Seeed_Studio_XIAO_ESP32C6.step` and linked it
  with the same transform in the local footprint and U3 PCB instance. Source
  dates, hashes, coordinate alignment, and licensing caveat are in
  [3d/README.md](3d/README.md). It is a 2024 model, not confirmation of the exact
  2026 schematic/purchased board revision; its `v7` label is not a hardware revision.
- All 14 castellation rows align. No nominal solid interference between the
  XIAO and carrier/other fitted parts; nearest component R24 is 1.82 mm away.
  HDMI shell tabs also clear the carrier substrate through their slots.
- Antenna projection is over the notch, with approximately 0.294 mm minimum
  planar distance to carrier material. This small margin is geometric only;
  physical Wi-Fi/enclosure/cable testing remains mandatory, not a CAD pass.
- Assembly model envelope is approximately 43.90 × 25.51 × 8.38 mm, including
  connector overhangs and shell tabs, excluding solder/cables. Added front/back
  renders, assembly STEP, and a hashed [solid-check report](hardware/rev2/checks/mechanical-3d.json).
- No schematic, land geometry, routing, board-outline, or BOM changes. U3 still
  counts as one purchased assembly; there are 12 fitted components.
- Verification: 0 ERC/DRC/parity/unrouted findings, 38 matching pin groups, and
  nine regression tests pass, including missing/rotated/misplaced model cases.
  `scripts/export_rev2.sh` now exports the 3D assets and hashes the local models.
  A separate optional OpenCascade audit refreshes the solid-check report; see
  [package instructions](hardware/rev2/README.md#repeat-the-solid-clearance-review).
- Unrelated `.history` changes were preserved. No commit, push, publication,
  fabrication order, physical test, or stage-3 firmware implementation was done.
- Next physical action: compare an actual XIAO/HDMI socket with the 1:1 print and
  model, check mating plugs/enclosure support, then run the power/USB/RF/DDC
  checklist. Next software action, when requested: stage 3 against the rev2 pins.

### 2026-09-12 — JLCPCB template and BOM preparation

Status: **CAD profile checked; JLCPCB assembly release blocked by sourcing and
placement/assembler approval.** Baseline `26b2222`; the user's `bom.csv` and
unrelated `.history` changes were already present and were preserved.

- Extracted the supplied template ZIP and inspected `JLCPCB_1-2Layer`. It is a
  2019 KiCad 5 snapshot that unexpectedly enables four copper layers. Kept the
  actual two-layer, 1.6 mm carrier and existing 0.20 mm track/clearance rules.
  Compared relevant limits with JLCPCB's current primary documentation. Applied
  the conservative 1 oz/green-mask profile in [JLCPCB notes](docs/jlcpcb.md).
- Strengthened via/ring/hole, mask and silk settings; enlarged/repositioned silk
  text and increased 33 silk graphics to 0.15 mm. No pad, route, via, footprint
  placement, board outline, or electrical-connectivity changes.
- Saved the six suitable user-selected MPN/LCSC groups (11 fitted parts) in the
  schematic and PCB. **J7's C516617 / PI3HDMI1310-AZLEX match is an IC, not the
  Würth 685119134923 connector.** It was not adopted. The existing connector is
  retained pending the user's sourcing/replacement choice.
- `bom.csv` stays byte-identical to the user's matching export. Regeneration now
  writes `bom-design.csv` and `bom-jlcpcb-draft.csv`; J7 stays in the draft with
  its correct MPN and blank LCSC code. The purchasing report remains blocked,
  and strict checking exits nonzero. Duplicate headers, ranged references, and
  multiline CSV fields are handled without silently choosing the wrong column.
- Verification: 0 ERC/DRC/parity/unrouted findings; 38 matching pin groups;
  16 regression tests pass (10 design, 6 BOM). Nominal 3D clearances unchanged;
  refreshed prototype outputs and source hashes. The solid-check report was
  still stale at this handoff and was corrected on 2026-09-13 below. No rule
  severity reductions, DRC exclusions, order, upload, reservation, commit, or push.
- Next action: resolve whether to source/consign the Würth connector, hand-fit it,
  or investigate a JLCPCB-stocked replacement (requires footprint review before
  adoption). Confirm XIAO reflow/handling, mixed SMT/slot soldering, service and
  tooling with JLCPCB. Economic's published size minimum accommodates 42 × 24 mm;
  Standard would require a panel/tooling solution. This is not an assembler approval.
- `positions-front.csv` remains raw KiCad data: custom U3/J7 origins need CPL
  offset/rotation verification and a placement-preview review before ordering.
  Physical fit/RF/power/DDC tests and stage-3 firmware remain unperformed.

### 2026-09-13 — JLCPCB verification and review workflow

Status: **CAD/preview checks pass; assembly sourcing and physical acceptance remain
pending.** Baseline `f5ea02e` contains the preceding JLCPCB preparation. Only the
unrelated `.history` changes were present at this session's start and were preserved.

- Confirmed all current source hashes and the byte-identical user `bom.csv`.
  The nominal solid report still referenced the pre-JLCPCB export; reran the
  pinned OpenCascade audit against the current STEP. All clearances are unchanged
  and the report now records the current STEP/PCB/manifest hashes. No CAD geometry,
  component choices or routing changes were made in this session.
- Replaced the attached workflow's KiCad 6 generator and obsolete Actions with
  the official KiCad 10.0.5 container and InteractiveHtmlBom 2.12.0. Dependencies
  are pinned by digest/commit. The official 10.0.6 image was not yet available.
  Both the local 10.0.6 build and exact 10.0.5 container build pass.
- Added a shared `validate_rev2.sh` gate used by the full prototype exporter and
  the new 2D review-site builder. It preserves the user matching CSV and permits
  only the known J7 exception for a draft. The site excludes the raw CSV, full
  fabrication package, placements and 3D assets; it labels the J7/assembly blockers.
- Pull requests produce review artifacts only; only `main` can upload/deploy
  Pages. Checkout credentials are not persisted, build permissions are read-only,
  and deploy permissions are isolated. Existing output directories are rejected
  to avoid overwriting user files or publishing stale assets.
- Verification: 0 ERC/DRC/parity/unrouted findings, 38 matching pin groups, and
  **18 passing tests** (10 design, 6 purchasing, 2 preview safety), including in
  the pinned container with a read-only project mount and no network. Inspected
  the interactive BOM in Firefox: 7 groups / 12 parts, correct J7 socket MPN with
  blank LCSC code, four test pads excluded. Index links, actionlint, ShellCheck,
  shell syntax and whitespace checks pass. Strict BOM checking still exits 1.
- Reproduction, dependencies and CI limitations are in [automation notes](docs/automation.md).
  No commit, push, GitHub run, artifact upload, Pages deployment, reservation,
  fabrication order, physical test or firmware implementation was performed.
- Next action still requires the J7 sourcing decision: retain the Würth socket
  for sourcing/consignment/hand-fitting, or authorize investigation of a stocked
  replacement and its footprint. Final CPL/assembler approval and physical tests
  remain outstanding. The owner can review/commit/push the workflow and verify
  GitHub Pages configuration separately; a green review is not assembly approval.

### 2026-09-13 — exact J7 catalog match and submission checklist

Status: **all 12 fitted part identities matched; final CPL and assembly-process
approval remain pending.** Baseline `9723b97`; unrelated `.history` changes preserved.

- The user supplied C2930961. Verified JLCPCB and LCSC identify it as the exact
  Würth 685119134923 already used by J7. Rechecked the manufacturer's land pattern:
  19 signal lands, 0.50 mm pitch, 0.28 × 2.60 mm pads and 14.50 mm shell-column
  spacing. Added only the hidden LCSC field in schematic/PCB; no footprint, slot,
  routing, outline, model or pin-mapping change.
- Corrected only J7's matching-CSV row on that selection. Cleared the old IC's
  pricing, stock/MOQ and account quantities; retained the user's quantity five.
  All other rows remain byte-identical. The original row is recoverable in Git
  history; export scripts still never overwrite the matching input. New CSV SHA-256:
  `41d7cd4179fb72cbd5afe507a82e5c78174dc66418836862444c5367fa45a1ee`.
- Updated the reviewed purchasing contract and removed the J7 export exception.
  Strict checking accepts all 12 current identities and still rejects the saved
  old IC snapshot. Added tests for accepting C2930961 and rejecting that code
  with a different footprint. The clean draft BOM now has seven fully matched
  groups; `ready_for_order` remains false because placement/process checks are separate.
- Regenerated the prototype package, source hashes and nominal 3D audit. All
  solid clearances remain unchanged. Full export and native/pinned-container
  preview builds pass: 0 ERC/DRC/parity/unrouted findings, 38 matching pin groups,
  and **20 tests** (10 design, 8 purchasing, 2 preview safety). No check exclusions.
- Updated README, package notes and the review site to distinguish matched parts
  from assembly approval. Recorded the normal three-file-set handoff in
  [JLCPCB submission notes](docs/jlcpcb.md#files-to-submit): fabrication ZIP
  including drills/outline, clean BOM, and finalized centroid/CPL from one revision.
- Next action: prepare/review the final JLCPCB CPL (column names plus U3/J7
  offsets/rotations), inspect the placement preview, and confirm complete-XIAO
  reflow/handling, four HDMI shell-tab solder joints, service/tooling and stock.
  `positions-front.csv` is still raw KiCad data, not an approved CPL. Physical
  bring-up and firmware remain separate pending stages. No order, upload,
  reservation, commit, push, GitHub deployment or physical test was performed.

### 2026-09-13 — JLCPCB draft CPL

Status: **JLCPCB-format draft CPL generated; U3/J7 centroid corrections, rotation
review and assembler approval remain pending.** Baseline `8b7c0f0` plus the user's
uncommitted CPL exporter, its tests and `export_rev2.sh` hook; `.history` preserved.

- Reviewed `scripts/export_jlcpcb_cpl.py` and `tests/test_jlcpcb_cpl.py` without
  changing them. The header, column order and `mm` values match JLCPCB's sample
  CPL; `Top`/`Bottom` is an accepted layer form and rotations stay counter-clockwise.
- Generated `hardware/rev2/cpl-jlcpcb-draft.csv` and `checks/jlcpcb-cpl.json` from
  the placement file and draft BOM, which match fresh KiCad 10.0.6 regenerations.
  All 12 designators match the BOM; XY and rotations are copied unchanged.
- JLCPCB defines Mid X/Mid Y as centroids. pcbnew shows only U3 and J7 differ from
  their pad centres (+8.917/+10.500 mm and +3.450/0 mm), so the unmodified draft
  would misplace them. Details are in the [JLCPCB notes](docs/jlcpcb.md).
- Verification: `validate_rev2.sh` passes locally, including ERC/DRC and 30 tests
  (10 design, 8 purchasing, 10 CPL, 2 preview safety). The pinned container build
  was not rerun.
- Next action: correct U3/J7 and check every rotation in JLCPCB's placement preview,
  then continue the assembly checklist. No order, upload, commit or push was made.

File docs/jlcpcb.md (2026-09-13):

# JLCPCB preparation — rev2

Factory/part review 2026-09-12; J7 confirmation and verification 2026-09-13.
**CAD checks pass; the assembly order is not ready.**
All 12 fitted component identities are now matched. Assembler acceptance,
current availability, and the final placement file still require confirmation.
No files were uploaded, no parts reserved, and no order placed.

## Template and board settings

The carrier really is **two copper layers**, 42 × 24 mm, nominal 1.6 mm FR-4.
The user-supplied `kicad_templates-master.zip` was extracted and its
`JLCPCB_1-2Layer` directory reviewed. This is a **KiCad 5 / 2019** snapshot,
archive commit `7a393457f57f22cc15bf484340ad554363761557`. Despite its name, both
its PCB and `.pro` file enable **four** copper layers (`CopperLayerCount=4`).
Its layer table, worksheet, legacy plot options, and whole project file were
therefore not imported into the working KiCad 10 design.

Archive SHA-256:

```text
9e39d52f667d11d42a962d5fce8701ad84b1f88ab81b73f83aa69e36a29d241f
```

The applied profile assumes **1 oz copper and green solder mask**. Other colors,
copper weights, finishes, or processes need a fresh review. These are local CAD
settings, not options already selected in a JLCPCB order.

| Setting, mm unless stated | Supplied template | Applied rev2 profile |
| --- | ---: | ---: |
| Copper layers | 4 (inconsistent with folder name) | 2, retained |
| Board thickness | 1.6002 | 1.6, retained |
| Minimum track / copper clearance | 0.127 / 0.127 | 0.20 / 0.20, retained |
| Minimum via diameter / drill | 0.60 / 0.30 | 0.60 / 0.30 |
| Minimum via annular width | Implicit 0.15 for default via | 0.15 |
| Minimum hole-to-hole clearance | 0.40 | 0.45, conservatively applied to all holes |
| Minimum hole-to-copper clearance | Not explicit | 0.28, conservatively applied globally |
| Copper-to-routed-edge clearance | Not explicit | 0.30, retained |
| Mask expansion / minimum web | 0 / 0.12 | 0 / 0.12 |
| Mask opening to neighboring copper | Not explicit | 0.09 |
| Minimum silkscreen text height / stroke | Defaults 0.8128 / 0.1524 | Constraints 1.0 / 0.15 |
| Silkscreen clearance | Not explicit | 0.15 |

Compared with JLCPCB's [current fabrication capabilities](https://jlcpcb.com/capabilities/pcb-capabilities):
the retained track/via choices have margin; current mask guidance permits 1:1
openings. Component PTH rings have a different requirement from via rings: the
HDMI shell lands were retained, not reduced to the via minimum. The antenna notch
and plated slots are routed features; this is not a V-scored panel.

Updated routing presets are 0.20/0.40/0.60/1.00 mm tracks and 0.60/0.30,
0.90/0.40 mm vias. Blind/buried vias and microvias remain disabled. Solder paste
expansion remains zero; vias remain tented, not specified as epoxy-filled.

The tighter checks initially found 38 silkscreen text/spacing issues. Enlarged
text, moved U4/SW2/SW3/TP references, and increased 33 footprint silkscreen
graphic strokes from 0.12 to 0.15 mm. The latter are PCB-instance styling changes;
refreshing standard footprints can reset them, so a regression check now guards
their minimum width. **Pads, traces, vias, component locations, outline, and
electrical connectivity were not changed.** No DRC exclusions or severity
reductions were used. Existing unrelated project preferences were preserved.

## Part selections

The user's [matching CSV](../hardware/rev2/bom.csv) is preserved except for the
explicit J7 correction below, based on the user's new selection on 2026-09-13.
Its duplicate `JLCPCB Part #` headers contain an empty input column and a populated
selected-part column; it also contains multiline descriptions and ranged
designators. It is a matching report, **not the clean upload BOM**.

| References | Manufacturer part / selected code | Review |
| --- | --- | --- |
| U3 | Seeed 113991254 / [C27675191](https://jlcpcb.com/partdetail/Seeed-113991254/C27675191) | Complete XIAO ESP32-C6; module handling/reflow and placement still need JLCPCB confirmation |
| U4 | TI TPD12S016PWR / [C201665](https://jlcpcb.com/partdetail/TexasInstruments-TPD12S016PWR/C201665) | Correct PW/TSSOP-24 part, not RKT/UQFN |
| SW2, SW3 | Omron B3U-1000P / [C231329](https://jlcpcb.com/partdetail/OmronElectronics-B3U1000P/C231329) | Matches the existing switch |
| R24, R25 | FOJAN FRH0603B1003TS / [C51048211](https://jlcpcb.com/partdetail/FOJAN-FRH0603B1003TS/C51048211) | 100 kΩ, 0.1 W, ±0.1%, 0603; meets design requirements |
| R26, R27 | Sunway SC0603F1002F2BNRH / [C3152123](https://jlcpcb.com/partdetail/Sunway-SC0603F1002F2BNRH/C3152123) | 10 kΩ, 0.1 W, ±1%, 0603; meets requirements |
| C1–C3 | YAGEO CC0603KRX7R9BB104 / [C14663](https://jlcpcb.com/partdetail/YAGEO-CC0603KRX7R9BB104/C14663) | 100 nF, 50 V, X7R, ±10%, 0603; exceeds the minimum 16 V requirement |
| J7 | Würth 685119134923 / [C2930961](https://jlcpcb.com/partdetail/WurthElektronik-685119134923/C2930961) | Exact existing HDMI Type A socket; no footprint substitution |

The passive-component warnings compare engineering values such as `100k` with
MPN strings. Those warnings do not by themselves indicate an electrical mismatch;
the actual selected specifications above were reviewed. Manufacturer/MPN/LCSC
fields for all seven groups (12 components) are saved in the schematic
and PCB. Stock, price, quoted order quantities, and setup fees are not pinned or
guaranteed by this review; the CSV's commercial data is only the user's snapshot.

J7 is the [Würth 685119134923 HDMI receptacle](https://www.we-online.com/components/products/datasheet/685119134923.pdf).
The user's **C2930961** selection was confirmed against the JLCPCB listing above
and [LCSC's catalog](https://www.lcsc.com/product-detail/C2930961.html), both of
which identify this exact manufacturer part. The manufacturer's land pattern
matches the existing 19 pads at 0.50 mm pitch, 0.28 × 2.60 mm signal lands, and
14.50 mm shell-tab column spacing. No pad, slot, outline, route or 3D-model change
is required. Its catalog listing specifies Economic/Standard SMT assembly, but
the four plated-slot shell tabs still need explicit soldering-process confirmation.

The original auto-match, PI3HDMI1310-AZLEX / C516617, was a switching IC and remains
rejected. Only J7's row was manually corrected in the matching CSV. Its obsolete
IC pricing, stock/MOQ and account-quantity fields were cleared, not transferred
to the socket; the user's requested quantity of five was retained. Other rows
remain byte-identical. Export/validation scripts still never rewrite this input.

## Files and export safety

- `hardware/rev2/bom.csv`: user-managed JLCPCB matching snapshot, never overwritten
  by the export script.
- [bom-design.csv](../hardware/rev2/bom-design.csv): generated engineering BOM with
  specifications and purchasing fields; 12 fitted parts.
- [bom-jlcpcb-draft.csv](../hardware/rev2/bom-jlcpcb-draft.csv): clean, uniquely
  headed **draft** using MPNs as comments, expanded references, and quantities per
  board. All seven groups / 12 components have reviewed codes, including J7
  `685119134923` / `C2930961`. It remains a draft until assembly review is complete.
- [BOM audit](../hardware/rev2/checks/jlcpcb-bom.json): records source hashes and
  all 12 reviewed identities. `unresolved_references` is empty, but
  `ready_for_order` remains false until the separate assembly checks are complete.
- [cpl-jlcpcb-draft.csv](../hardware/rev2/cpl-jlcpcb-draft.csv): generated from
  `positions-front.csv` and checked against the draft BOM's 12 designators. Its
  header, column order and `mm` values follow JLCPCB's sample CPL; XY and rotations
  are copied unchanged. The [CPL report](../hardware/rev2/checks/jlcpcb-cpl.json)
  records input hashes and keeps `ready_for_order` false.

The column format follows JLCPCB's [KiCad export guide](https://jlcpcb.com/help/article/how-to-generate-the-bom-and-centroid-file-from-kicad)
and [placement-file guide](https://jlcpcb.com/help/article/pick-place-file-for-pcb-assembly).
`positions-front.csv` remains **raw KiCad placement data**, and the draft CPL is only
a column/unit conversion, not an approved JLCPCB CPL. JLCPCB defines Mid X/Mid Y as
the component centroid, but the U3 and J7 footprint origins are not centroids:

| Ref | Draft CPL XY, mm | Pad-area centre, mm | Difference, mm |
| --- | --- | --- | --- |
| U3 | 52.000, -71.037 | 60.917, -60.537 | +8.917, +10.500 |
| J7 | 82.500, -62.000 | 85.950, -62.000 | +3.450, 0 (courtyard centre +4.375, 0) |

The other ten footprint origins coincide with their pad and courtyard centres.
Before an order, correct U3/J7 against JLCPCB's part models and verify every
rotation in the placement preview, including pin 1, USB direction, and HDMI direction.

```sh
bash scripts/export_rev2.sh
sha256sum -c hardware/rev2/checks/source-sha256.txt
# Strict purchasing-identity check: now exits 0; this is not assembly approval.
python3 scripts/check_jlcpcb_bom.py hardware/rev2/bom.csv hardware/rev2/checks/netlist.xml \
  --report hardware/rev2/checks/jlcpcb-bom.json
```

Every purchasing identity/footprint mismatch now stops the main export; the old
J7 exception has been removed. Update purchasing fields and the reviewed part contract
together after approving a new selection. Re-export and refresh the separate
solid-check report as described in the [package README](../hardware/rev2/README.md).

## Files to submit

Yes: the normal JLCPCB handoff is **one fabrication ZIP plus a BOM and a CPL**.
Keep all three synchronized to the same reviewed design revision.

| Upload | Contents / current project file |
| --- | --- |
| Fabrication ZIP | ZIP the contents of `hardware/rev2/fabrication/`: copper, solder mask, silkscreen, paste, outline **and `.drl` drill files**. Keep the antenna cutout and HDMI plated-slot routing; drill-map PDFs and `.gbrjob` are supplementary. |
| BOM | Use the clean `hardware/rev2/bom-jlcpcb-draft.csv` for matching/review, not the duplicate-header `bom.csv` matching report. It now includes C2930961 and all 12 fitted parts; finalize the order only after assembly signoff. |
| Centroid / CPL / pick-and-place | Finalize from `hardware/rev2/cpl-jlcpcb-draft.csv` (`Designator,Mid X,Mid Y,Layer,Rotation`, mm), generated from `positions-front.csv`. Apply the U3/J7 centroid corrections and verify all rotations first; the draft is **not the finalized upload CPL**. |

This follows JLCPCB's [Gerber/drill guide](https://jlcpcb.com/help/article/how-to-generate-gerber-and-drill-files-in-kicad-9)
and [BOM/CPL guide](https://jlcpcb.com/help/article/how-to-generate-the-bom-and-centroid-file-from-kicad).
J7 is mixed SMT/plated-slot, so keep it in the placement list even though KiCad
marks the footprint through-hole. TP1–TP4 are etched test pads, not purchased parts.
No schematic or STEP upload is normally part of these three required file sets;
an assembly drawing or process note can support the XIAO/HDMI handling review.

File upload alone is not the final approval: select/confirm the two-layer 1.6 mm,
1 oz/green-mask board options and assembly service, check the Gerber preview and
part matches, and inspect placement orientation before paying. In particular,
verify USB direction, HDMI direction and pin 1, and agree on XIAO reflow handling
and soldering all four HDMI shell tabs. No files were submitted by this work.

## Assembly decisions still required

JLCPCB currently lists **10 × 10 mm minimum for Economic PCBA**, versus
**70 × 70 mm for Standard PCBA**; single-sided SMT/through-hole assembly is listed
for Economic. Thus this 42 × 24 mm carrier meets Economic's size requirement, but
that alone does not establish acceptance of these parts. Standard would require
a suitable larger panel/tooling arrangement. Their [assembly capabilities](https://jlcpcb.com/capabilities/pcb-assembly-capabilities)
also distinguish tooling/fiducial requirements by service.

- [x] Resolve J7's exact catalog identity: Würth 685119134923 / C2930961.
- [ ] Confirm current J7 availability and explicitly include soldering its four
  plated-slot shell tabs, not just its SMT contacts.
- [ ] Have JLCPCB confirm placement and the soldering profile for the **complete
  XIAO module**; a catalog listing is not approval of this custom carrier mounting.
- [ ] Confirm Economic versus Standard, actual component availability, finish,
  stencil, handling of the notched outline/overhanging connectors, and any panel,
  rails, fiducials, or tooling holes. Do not enlarge the carrier just to match the
  Standard minimum without choosing that process first.
- [x] Convert placements to JLCPCB's CPL columns: `cpl-jlcpcb-draft.csv`.
- [ ] Correct U3/J7 centroids, verify all rotations, and inspect JLCPCB's placement
  preview before paying.
- [ ] Perform the existing physical fit, power, USB, RF, and monitor checks.

The carrier itself has no castellated edge holes: the castellations belong to
the purchased XIAO. Do not select special carrier edge-plating/castellation
fabrication solely because the module uses castellated mounting.

Validation: KiCad 10.0.6 ERC/DRC/parity/unrouted **0 findings**, 38 matching pin
groups, and **20 regression tests pass** (10 design, 8 BOM, 2 preview safety).
The [review workflow](automation.md) also passes the same checks in its pinned
KiCad 10.0.5 container. Nominal 3D clearances are unchanged and the separate
solid report now matches the current STEP/source hashes. This is CAD/purchasing
preparation, not JLCPCB DFM/DFA approval or a physical test.

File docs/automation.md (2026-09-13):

# Rev2 review automation

Updated 2026-09-13. The [workflow](../.github/workflows/main.yml) builds a **CAD
review preview**, not an approved fabrication/assembly package. A green run does
not resolve the [JLCPCB placement and assembly checks](jlcpcb.md).

## What runs

Pushes to `main`, pull requests targeting `main`, and manual workflow runs:

1. Use the official KiCad **10.0.5** container, pinned by digest, and
   InteractiveHtmlBom **2.12.0**, pinned by commit. The official registry did not
   yet have 10.0.6; local CAD work uses 10.0.6. Both were tested below.
2. Run `scripts/validate_rev2.sh`: ERC, DRC/parity/unrouted checks, the 38-group
   electrical contract, footprint/model/keepout/silk checks, and 20 regression
   tests (10 design, 8 purchasing, 2 preview-output safety tests).
3. Audit the matching CSV without changing it. All 12 fitted part identities
   must match; the former J7 exception is removed after confirming C2930961.
4. Generate an interactive BOM, schematic PDF, engineering BOM, clearly named
   JLCPCB draft BOM, and reports into a **new** `out/` directory. J7 retains its
   correct socket MPN with C2930961. Test pads do not count as fitted parts.
5. Retain diagnostics even after a failed check. Upload a review preview only
   after a successful build. Upload/deploy Pages **only from `main`, never from a
   pull request**. A manual run on another branch produces a preview only.

The build token has read-only repository permissions and checkout credentials
are not persisted. Only the separate deploy job has Pages/OIDC write permissions.
Pull-request builds can cancel superseded PR builds; Pages deployments are serialized.
No workflow was dispatched, pushed, or deployed during this local work. Actual
GitHub-hosted execution and the repository's Pages/environment settings remain to
be verified by the owner after committing/pushing the changes.

## What is deliberately excluded

The site does not copy `hardware/rev2/` wholesale. It excludes the raw user matching
CSV, Gerbers, raw placements/CPL, STEP files and 3D renders. The supplied model's
[redistribution caveat](../3d/README.md) is unchanged. CI neither refreshes nor
claims to run the optional OpenCascade solid audit; it only checks the pinned
local model and its CAD transform as part of the regular design contract.

The full prototype exporter still uses `scripts/export_rev2.sh`. Its validation
gate is now shared with CI, and it still never overwrites `hardware/rev2/bom.csv`.
The [separate solid audit](../hardware/rev2/README.md#repeat-the-solid-clearance-review)
must be rerun after exporting new STEP geometry. A review site is not a substitute
for that package or for physical hardware tests.

## Local preview

With KiCad 10, its standard symbol/footprint libraries and `pcbnew` Python module
installed, run from the project root:

```sh
preview_dir="$(mktemp -d -t hdmi2c-preview.XXXXXX)"
git clone --no-checkout https://github.com/openscopeproject/InteractiveHtmlBom.git \
  "$preview_dir/InteractiveHtmlBom"
git -C "$preview_dir/InteractiveHtmlBom" checkout --detach \
  5c192e794cd66fde04bab11810601b711bf8581b
bash scripts/build_review_site.sh "$preview_dir/InteractiveHtmlBom" "$preview_dir/site"
# Open the generated site/index.html in a browser.
```

The builder refuses an existing output directory rather than deleting it or
mixing in stale assets. Choose a new path on each run. An export failure may leave
partial diagnostics there, but CI will not upload it as a successful site.
To run checks without building a site:

```sh
validation_dir="$(mktemp -d -t hdmi2c-checks.XXXXXX)"
bash scripts/validate_rev2.sh "$validation_dir"
```

## Verification and dependency provenance

- Complete headless preview builds passed locally on KiCad 10.0.6 and in the
  **exact pinned 10.0.5 container**, with a read-only project mount and networking
  disabled for the container build. Both returned zero ERC/DRC/parity/unrouted
  findings, 38 matching pin groups, and 20 passing tests.
- Inspected the generated interactive BOM in Firefox: 7 groups / 12 fitted parts,
  four test pads excluded, correct J7 socket MPN and C2930961 purchasing code.
  All review-index links resolve. Strict identity checking exits 0; the old
  incorrect IC snapshot still fails. Assembly approval remains separate.
- `actionlint` 1.7.12, ShellCheck, shell syntax and whitespace checks pass. These
  local checks do not test GitHub authentication, artifact uploads or deployment.
- The matching CSV's J7 row was explicitly corrected on the user's selection of
  C2930961; all other rows are unchanged. Export scripts never rewrite it.
  The current digest is recorded in `hardware/rev2/checks/source-sha256.txt`.

The removed upstream generator [installs KiCad 6](https://github.com/wlcx/kicad-site-generator/blob/main/Dockerfile).
The replacement uses [KiCad's official container distribution](https://www.kicad.org/download/docker/)
and [InteractiveHtmlBom 2.12.0](https://github.com/openscopeproject/InteractiveHtmlBom/releases/tag/v2.12.0).
Official actions are pinned to verified release commits: [checkout 7.0.1](https://github.com/actions/checkout/releases/tag/v7.0.1),
[upload-artifact 7.0.1](https://github.com/actions/upload-artifact/releases/tag/v7.0.1),
[upload-pages-artifact 5.0.0](https://github.com/actions/upload-pages-artifact/releases/tag/v5.0.0),
and [deploy-pages 5.0.1](https://github.com/actions/deploy-pages/releases/tag/v5.0.1).
Dependency updates require a new preview build and review; none floats on `main`.

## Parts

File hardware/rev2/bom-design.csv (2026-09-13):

References | Value | Footprint | Quantity | Manufacturer | MPN | LCSC Part # | Specification | Datasheet
C1-C3 | 100nF | Capacitor_SMD:C_0603_1608Metric | 3 | YAGEO | CC0603KRX7R9BB104 | C14663 | 100 nF; >=16 V; X7R; +/-10%; 0603
J7 | HDMI1 | hdmi2c:WURTH_685119134923_HDMI | 1 | Wurth Elektronik | 685119134923 | C2930961 | HDMI Type A receptacle; SMT contacts and plated-slot shell tabs | https://www.we-online.com/components/products/datasheet/685119134923.pdf
R24,R25 | 100k | Resistor_SMD:R_0603_1608Metric | 2 | FOJAN | FRH0603B1003TS | C51048211 | 100 kohm; >=0.1 W; +/-1%; 0603
R26,R27 | 10k | Resistor_SMD:R_0603_1608Metric | 2 | Sunway | SC0603F1002F2BNRH | C3152123 | 10 kohm; >=0.1 W; +/-1%; 0603
SW2,SW3 | B3U-1000P | Button_Switch_SMD:SW_SPST_B3U-1000P | 2 | Omron | B3U-1000P | C231329 | Top-actuated SPST-NO; no locating boss | https://omronfs.omron.com/en_US/ecb/products/pdf/en-b3u.pdf
U3 | XIAO ESP32-C6 | hdmi2c:XIAO_ESP32C6_Castellated | 1 | Seeed Studio | 113991254 | C27675191 | Complete V1.0 module; 14 soldered castellations; 4 MB flash | https://files.seeedstudio.com/wiki/SeeedStudio-XIAO-ESP32C6/XIAO_ESP32_C6_v1.0_SCH_260114.pdf
U4 | TPD12S016PWR | Package_SO:TSSOP-24_4.4x7.8mm_P0.65mm | 1 | Texas Instruments | TPD12S016PWR | C201665 | PW/TSSOP-24; do not substitute the RKT pinout | https://www.ti.com/lit/ds/symlink/tpd12s016.pdf

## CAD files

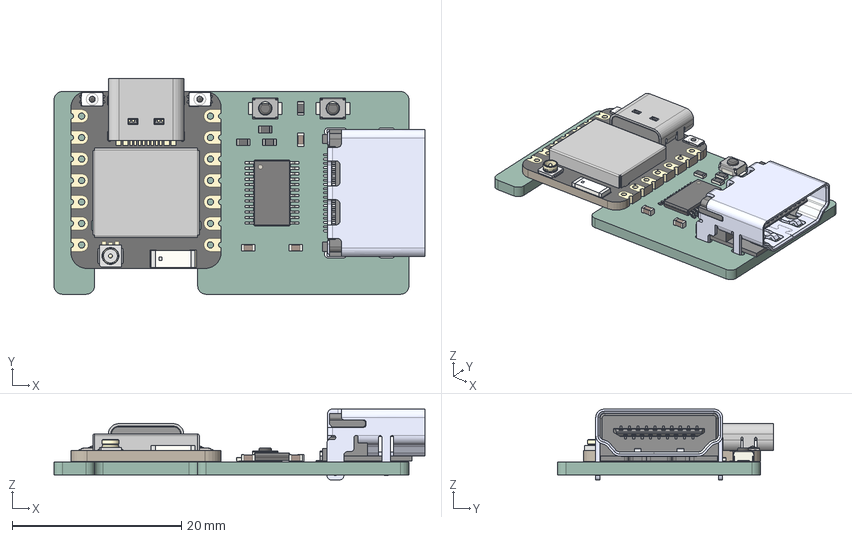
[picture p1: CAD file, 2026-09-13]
hardware/rev2/assembly.step
43.9 x 25.5 x 8.38 mm
SW_SPST_B3U-1000P x 2
R_0603_1608Metric x 4
TSSOP-24_4.4x7.8mm_P0.65mm
BOSS-EXTRUDE14_8_
BOSS-EXTRUDE7_4_
BOSS-EXTRUDE7_3_
BOSS-EXTRUDE14_4_
BOSS-EXTRUDE14_2_
BOSS-EXTRUDE14_11_
BOSS-EXTRUDE7_7_
BOSS-EXTRUDE14_9_
BOSS-EXTRUDE14_3_
BOSS-EXTRUDE14_7_
MIRROR2
BOSS-EXTRUDE14_5_
BOSS-EXTRUDE14_12_
BOSS-EXTRUDE7_8_
BOSS-EXTRUDE7_1_
BOSS-EXTRUDE14_10_
BOSS-EXTRUDE7_9_
BOSS-EXTRUDE14_6_
BOSS-EXTRUDE14_1_
BOSS-EXTRUDE7_6_
BOSS-EXTRUDE7_2_
CUT-EXTRUDE5
BOSS-EXTRUDE7_5_
U.FL Connector v1
Shield
SKTAAAE010 v1 x 2
KH5220-A36 (Ceramic Antenna) v2
C_0603_1608Metric x 3
hdmi2c_PCB

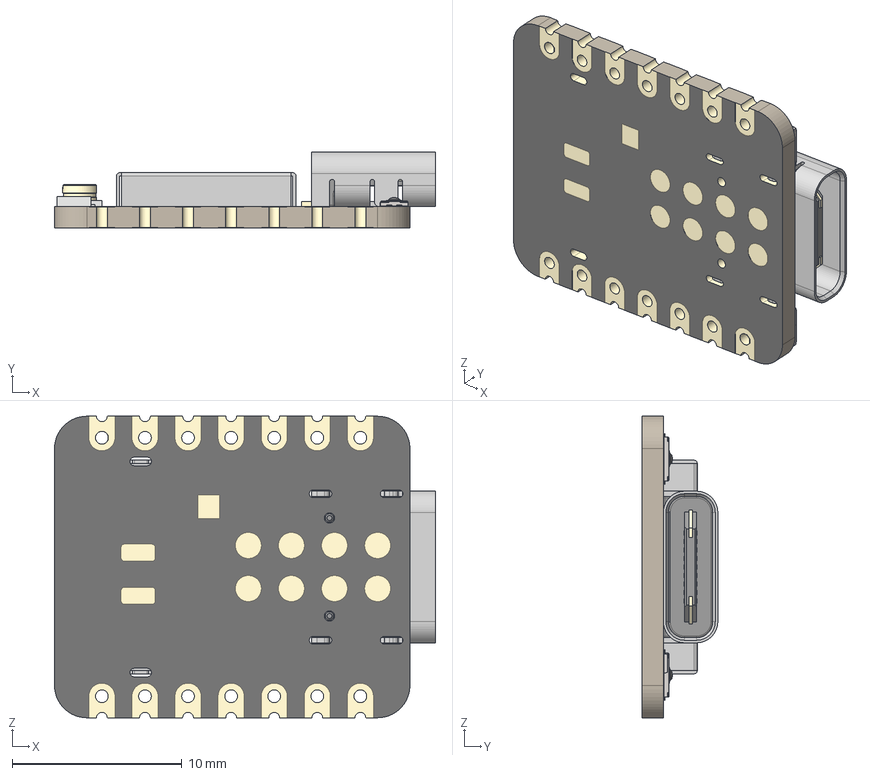
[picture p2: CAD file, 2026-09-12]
3d/Seeed_Studio_XIAO_ESP32C6.step
22.5 x 4.46 x 17.8 mm
BOSS-EXTRUDE14_8_
BOSS-EXTRUDE7_4_
BOSS-EXTRUDE7_3_
BOSS-EXTRUDE14_4_
BOSS-EXTRUDE14_2_
BOSS-EXTRUDE14_11_
BOSS-EXTRUDE7_7_
BOSS-EXTRUDE14_9_
BOSS-EXTRUDE14_3_
BOSS-EXTRUDE14_7_
MIRROR2
BOSS-EXTRUDE14_5_
BOSS-EXTRUDE14_12_
BOSS-EXTRUDE7_8_
BOSS-EXTRUDE7_1_
BOSS-EXTRUDE14_10_
BOSS-EXTRUDE7_9_
BOSS-EXTRUDE14_6_
BOSS-EXTRUDE14_1_
BOSS-EXTRUDE7_6_
BOSS-EXTRUDE7_2_
CUT-EXTRUDE5
BOSS-EXTRUDE7_5_
U.FL Connector v1
Shield
SKTAAAE010 x 2
KH5220-A36 (Ceramic Antenna) v2

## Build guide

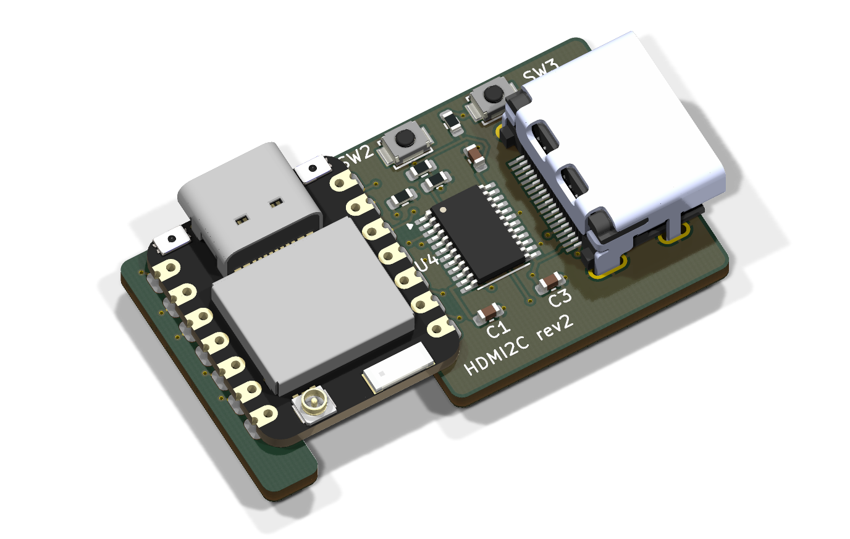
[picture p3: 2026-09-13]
hardware/rev2/assembly-3d-front.png

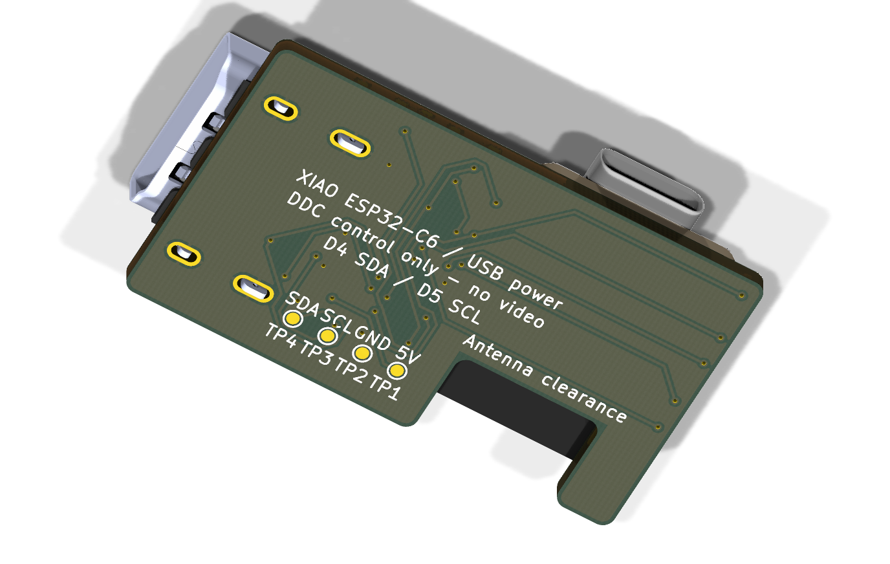
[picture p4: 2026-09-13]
hardware/rev2/assembly-3d-back.png

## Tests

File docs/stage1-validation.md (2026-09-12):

# Single-HDMI hardware revision

Revision: `rev1`, 2026-09-12. Stage 1 is complete in CAD. This is an intermediate
ESP32-WROOM-32 design; the XIAO carrier and ESPHome firmware are still planned.
The board has not been built or tested on a monitor, and the inherited findings
below must be reviewed before fabrication.

## Changes

- Kept HDMI1 (`J7`) and its complete DDC level shifting, HPD divider, shield jumper,
  switchable 5 V supply, and I2C jumpers.
- Removed `J8`, `JP2`, `JP7`, `JP8`, `Q4`, `Q6`, `Q8`, `R8`, `R10`, `R12`,
  `R14`, `R20`, `R21`, `U5`, and `C6` from schematic and PCB, together with their
  nets and routing. Removed dedicated branches of the shared power/ground nets.
- Marked U3 pins 8, 9, 28, and 31 (GPIO32, GPIO33, GPIO17, GPIO19) as intentionally
  unconnected. Their old HDMI2/I2C2 signal labels and traces are gone.
- Reduced the outline from 95 × 45 mm to 70 × 45 mm: 4,275 to 3,150 mm², a 26.3%
  area reduction. Moved the two right mounting holes 25 mm left while preserving
  the corner radius and hole-to-edge spacing.
- Moved the copper logo above the MCU, scaled it to 80%, and updated its revision
  glyph to `rev1`. Updated the local footprint library to match. The original
  creator's name and 2021 artwork attribution remain.
- Refilled the bottom ground plane. Kept the original schematic format 20211123
  and PCB format 20211014, without a wholesale KiCad format conversion.
- Reduced the populated circuit from 56 to 41 component footprints. Total PCB
  footprints went from 61 to 46, including four mounting holes and one logo.

## Retained pin mapping

This table is for the stage-1 WROOM design. Stage 2 will define the XIAO mapping.

| Function | ESP32-WROOM-32 | HDMI connector / path |
| --- | --- | --- |
| DDC SCL | GPIO26, U3 pin 11 | JP3 → Q3 → J7 pin 15 |
| DDC SDA | GPIO27, U3 pin 12 | JP4 → Q5 → J7 pin 16 |
| HPD sense | GPIO16, U3 pin 27 | J7 pin 19 → R18/R19 divider |
| HDMI 5 V enable | GPIO18, U3 pin 30 | U4 enable → Q7 → J7 pin 18 |
| DDC ground | GND | J7 pin 17 |

## Verification results

Compared against the original schematic/PCB at commit
`3f064aa6c761e88b313b9f9e71b1f0dff42e0744`, using the user's existing project
settings and KiCad CLI 10.0.6. The existing `hdmi2c.kicad_pro` changes were preserved
byte-for-byte. Both baseline and revised DRC runs refilled zones.

| Check | Original | Stage 1 |
| --- | ---: | ---: |
| HDMI connectors | 2 | 1 |
| Unrouted connections (DRC) | 0 | 0 |
| ERC errors | 12 | 7 |
| ERC warnings | 351 | 257 |
| DRC errors | 18 | 10 |
| DRC warnings | 58 | 41 |
| Schematic/PCB parity warnings | 115 | 90 |
| New ERC/DRC/parity findings, compared by rule and item UUIDs | — | 0 |

Independent connectivity comparison passed for all **88 remaining pin groups**:

1. The PCB's assigned pin groups match the exported schematic netlist.
2. The revised schematic equals the original schematic after removing the 15
   deleted components. Every retained pin connection, including the complete
   HDMI1 and shared supply circuits, is preserved.

This comparison deliberately ignores automatic net-name spelling, which differs
between KiCad generations. Physical routing was checked separately by DRC.
Schematic PDF/SVG and PCB copper/outline views exported successfully and were
visually inspected. `git diff --check` passed.

## Inherited findings to resolve before a release

- Seven ERC power-drive errors: J7's four TMDS shield pins, HDMI1 5 V, and the
  GND/VBUS supply declarations. The shield nets are currently isolated labels;
  review the electrical intent and power flags during the XIAO redesign.
- Eight DRC errors concern copper bridges in the retained JP3/JP4 solder-jumper
  footprints: four solder-mask bridge, two clearance, and two shorting findings.
  These are the original bridged-jumper geometry and net representation; review
  the footprint/net-tie modeling rather than suppressing the entire rule.
- Two DRC errors are the existing C3 courtyard overlaps with J1 and U1 in the
  USB/serial section. This section is due to be replaced by the XIAO.
- Remaining ERC warnings: 216 off-grid endpoints, 33 symbol-library mismatches,
  five isolated labels, and three symbol-library issues.
- Remaining DRC warnings: 39 footprint-library mismatches and two silkscreen
  edge-clearance findings.
- Parity warnings: 76 legacy net-name differences, nine datasheet-field
  differences, and five PCB-only footprints (mounting holes and artwork).

These counts are recorded findings, not a claim of a clean manufacturing check.
No rule severities or exclusions were changed to obtain the results. Stage 2
must review the power circuit and resolve remaining release-blocking findings;
physical power, DDC, and monitor compatibility tests are still outstanding.

## Repeating the checks

From the repository root, with KiCad CLI and its `pcbnew` Python module installed:

```sh
task_checks="$(mktemp -d)"
kicad-cli sch export netlist --format kicadxml \
  -o "$task_checks/netlist.xml" hdmi2c.kicad_sch
python3 scripts/check_connectivity.py hdmi2c.kicad_pcb "$task_checks/netlist.xml"
kicad-cli sch erc --format json \
  -o "$task_checks/erc.json" hdmi2c.kicad_sch
kicad-cli pcb drc --refill-zones --schematic-parity --format json \
  -o "$task_checks/drc.json" hdmi2c.kicad_pcb
git diff --check
```

Inspect the JSON reports: the CLI normally exits successfully even when it finds
violations. Add `--exit-code-violations` for a strict gate, which currently fails
on the inherited findings. Avoid `--save-board` on the working file unless a
KiCad format migration is intended.

The connectivity helper also accepts `--baseline-netlist <original.xml>` and
`--removed J8 JP2 JP7 JP8 Q4 Q6 Q8 R8 R10 R12 R14 R20 R21 U5 C6` to repeat the
stage-1 preservation check using an exported original netlist. It does not replace
ERC, DRC, or physical measurements.

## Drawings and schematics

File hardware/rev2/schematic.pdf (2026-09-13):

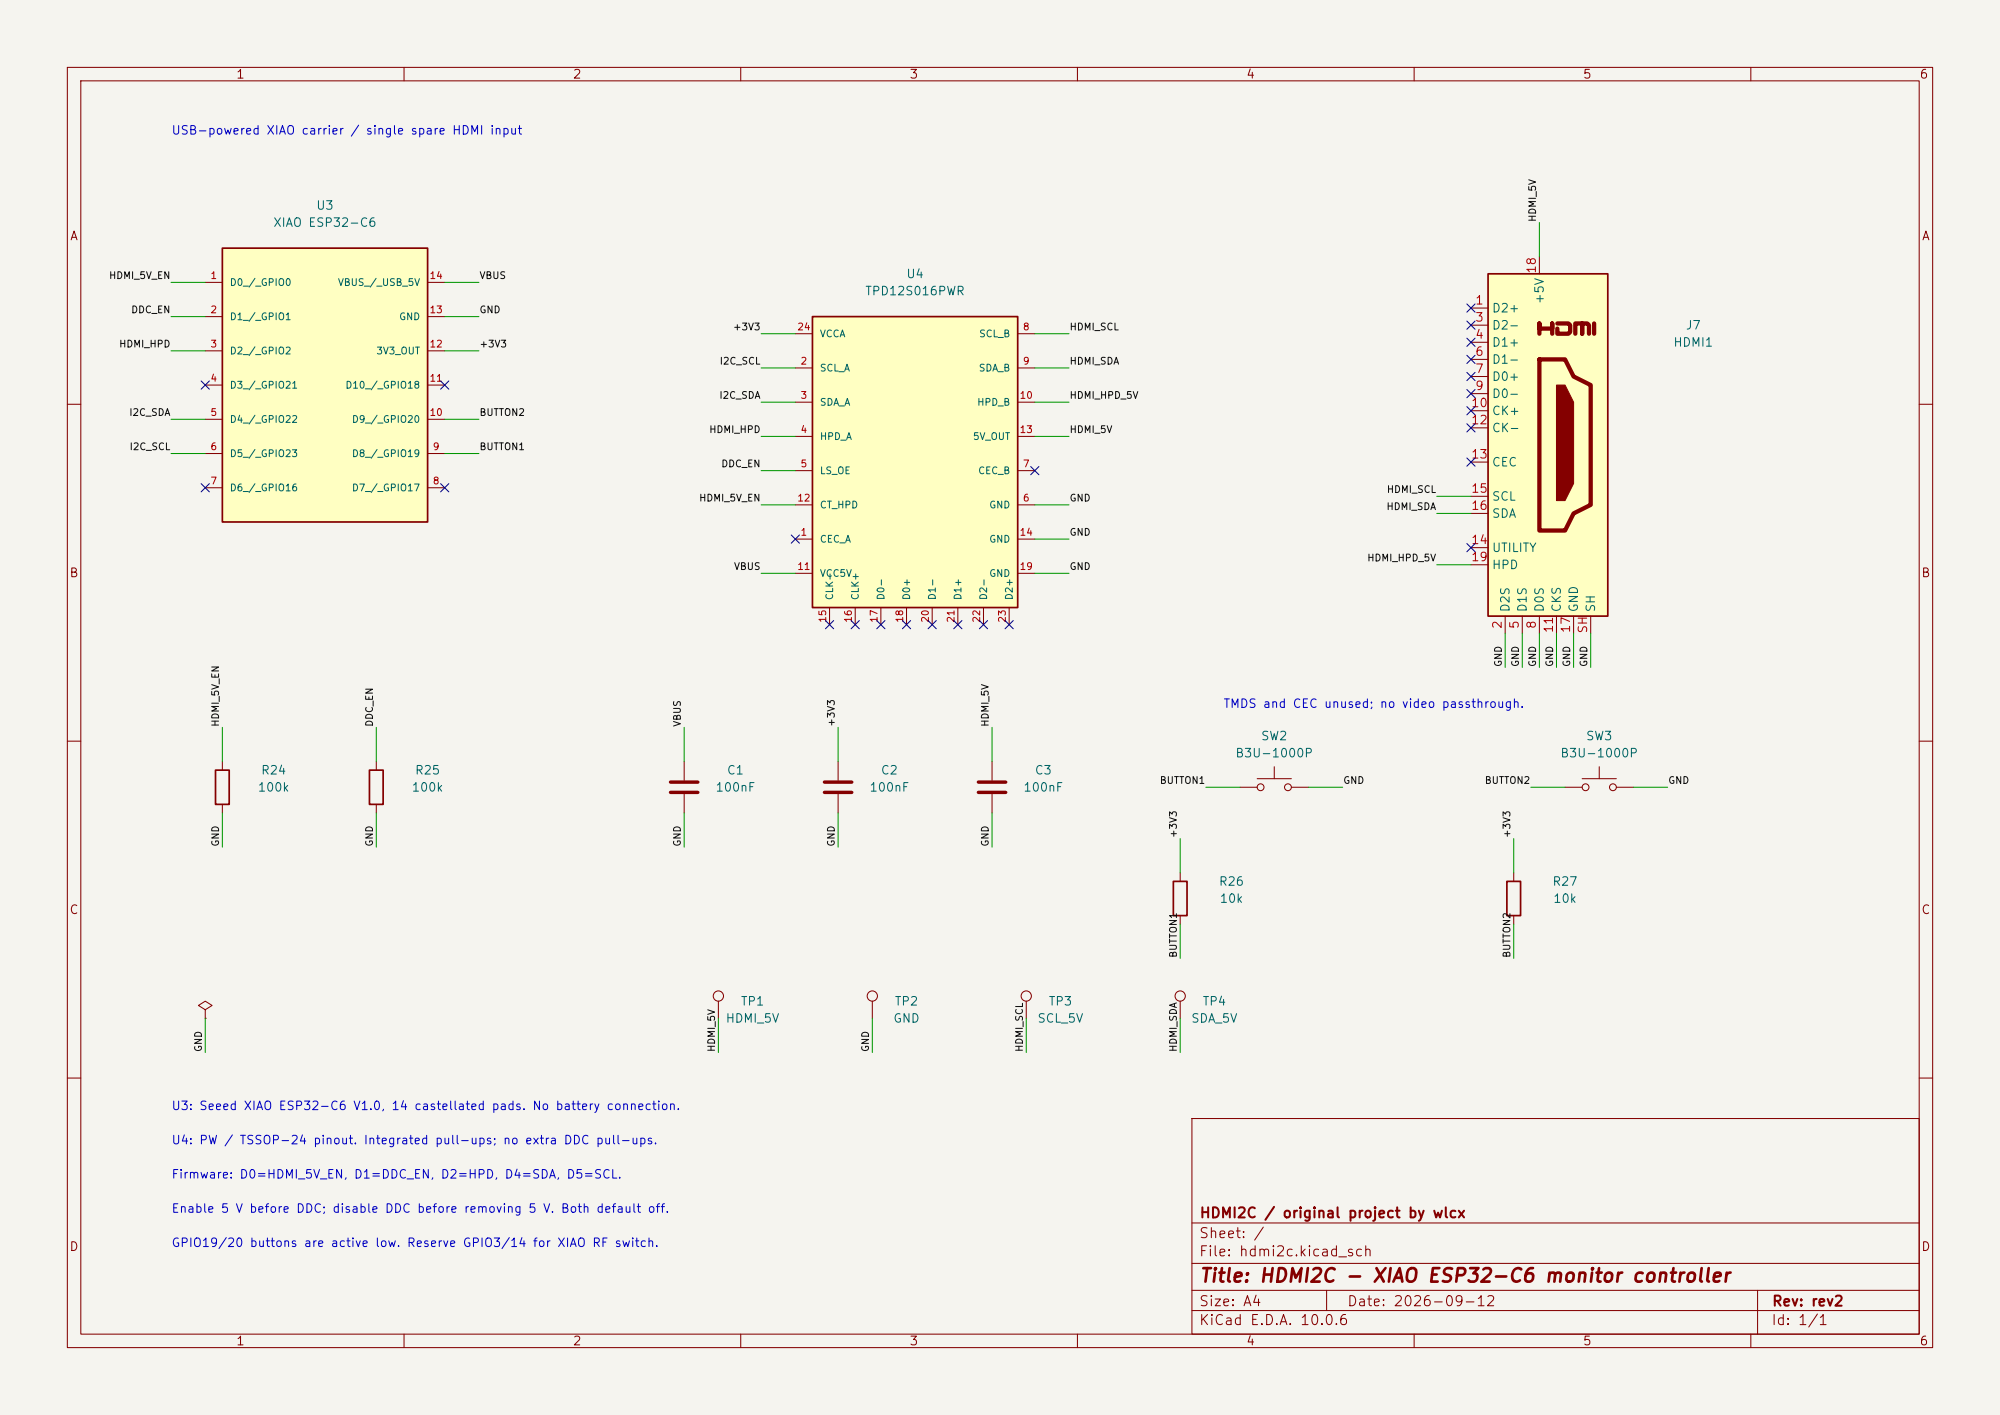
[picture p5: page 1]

USB-powered XIAO carrier / single spare HDMI input

8 D0- 9 CK+ 10 CKS 11 CK- 12 CEC 13 UTILITY 14

TMDS and CEC unused; no video passthrough.

HDMI2C / original project by wlcx
Sheet: /
File: hdmi2c.kicad_sch
Title: HDMI2C - XIAO ESP32-C6 monitor controller

Size: A4 | Rev: rev2
KiCad E.D.A. 10.0.6 | Id: 1/1

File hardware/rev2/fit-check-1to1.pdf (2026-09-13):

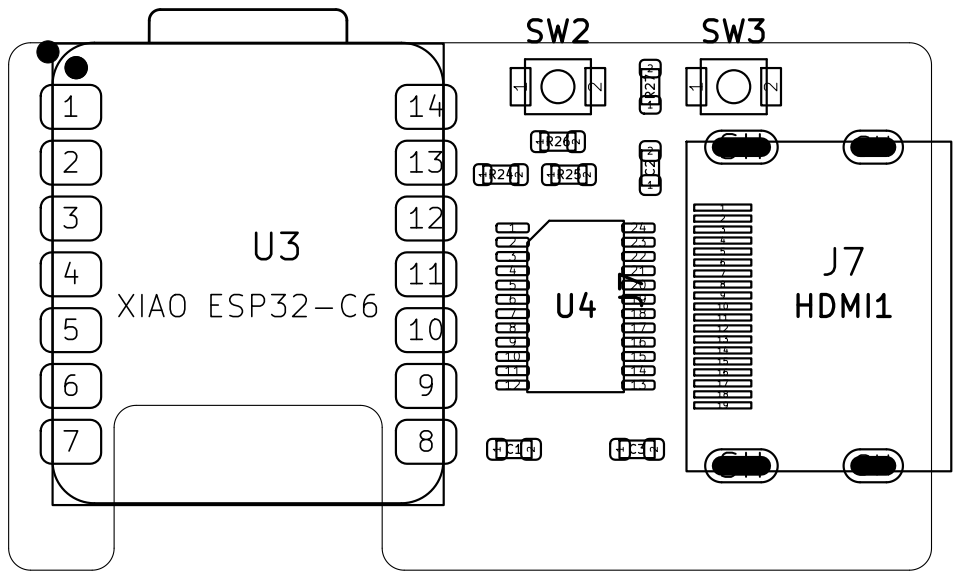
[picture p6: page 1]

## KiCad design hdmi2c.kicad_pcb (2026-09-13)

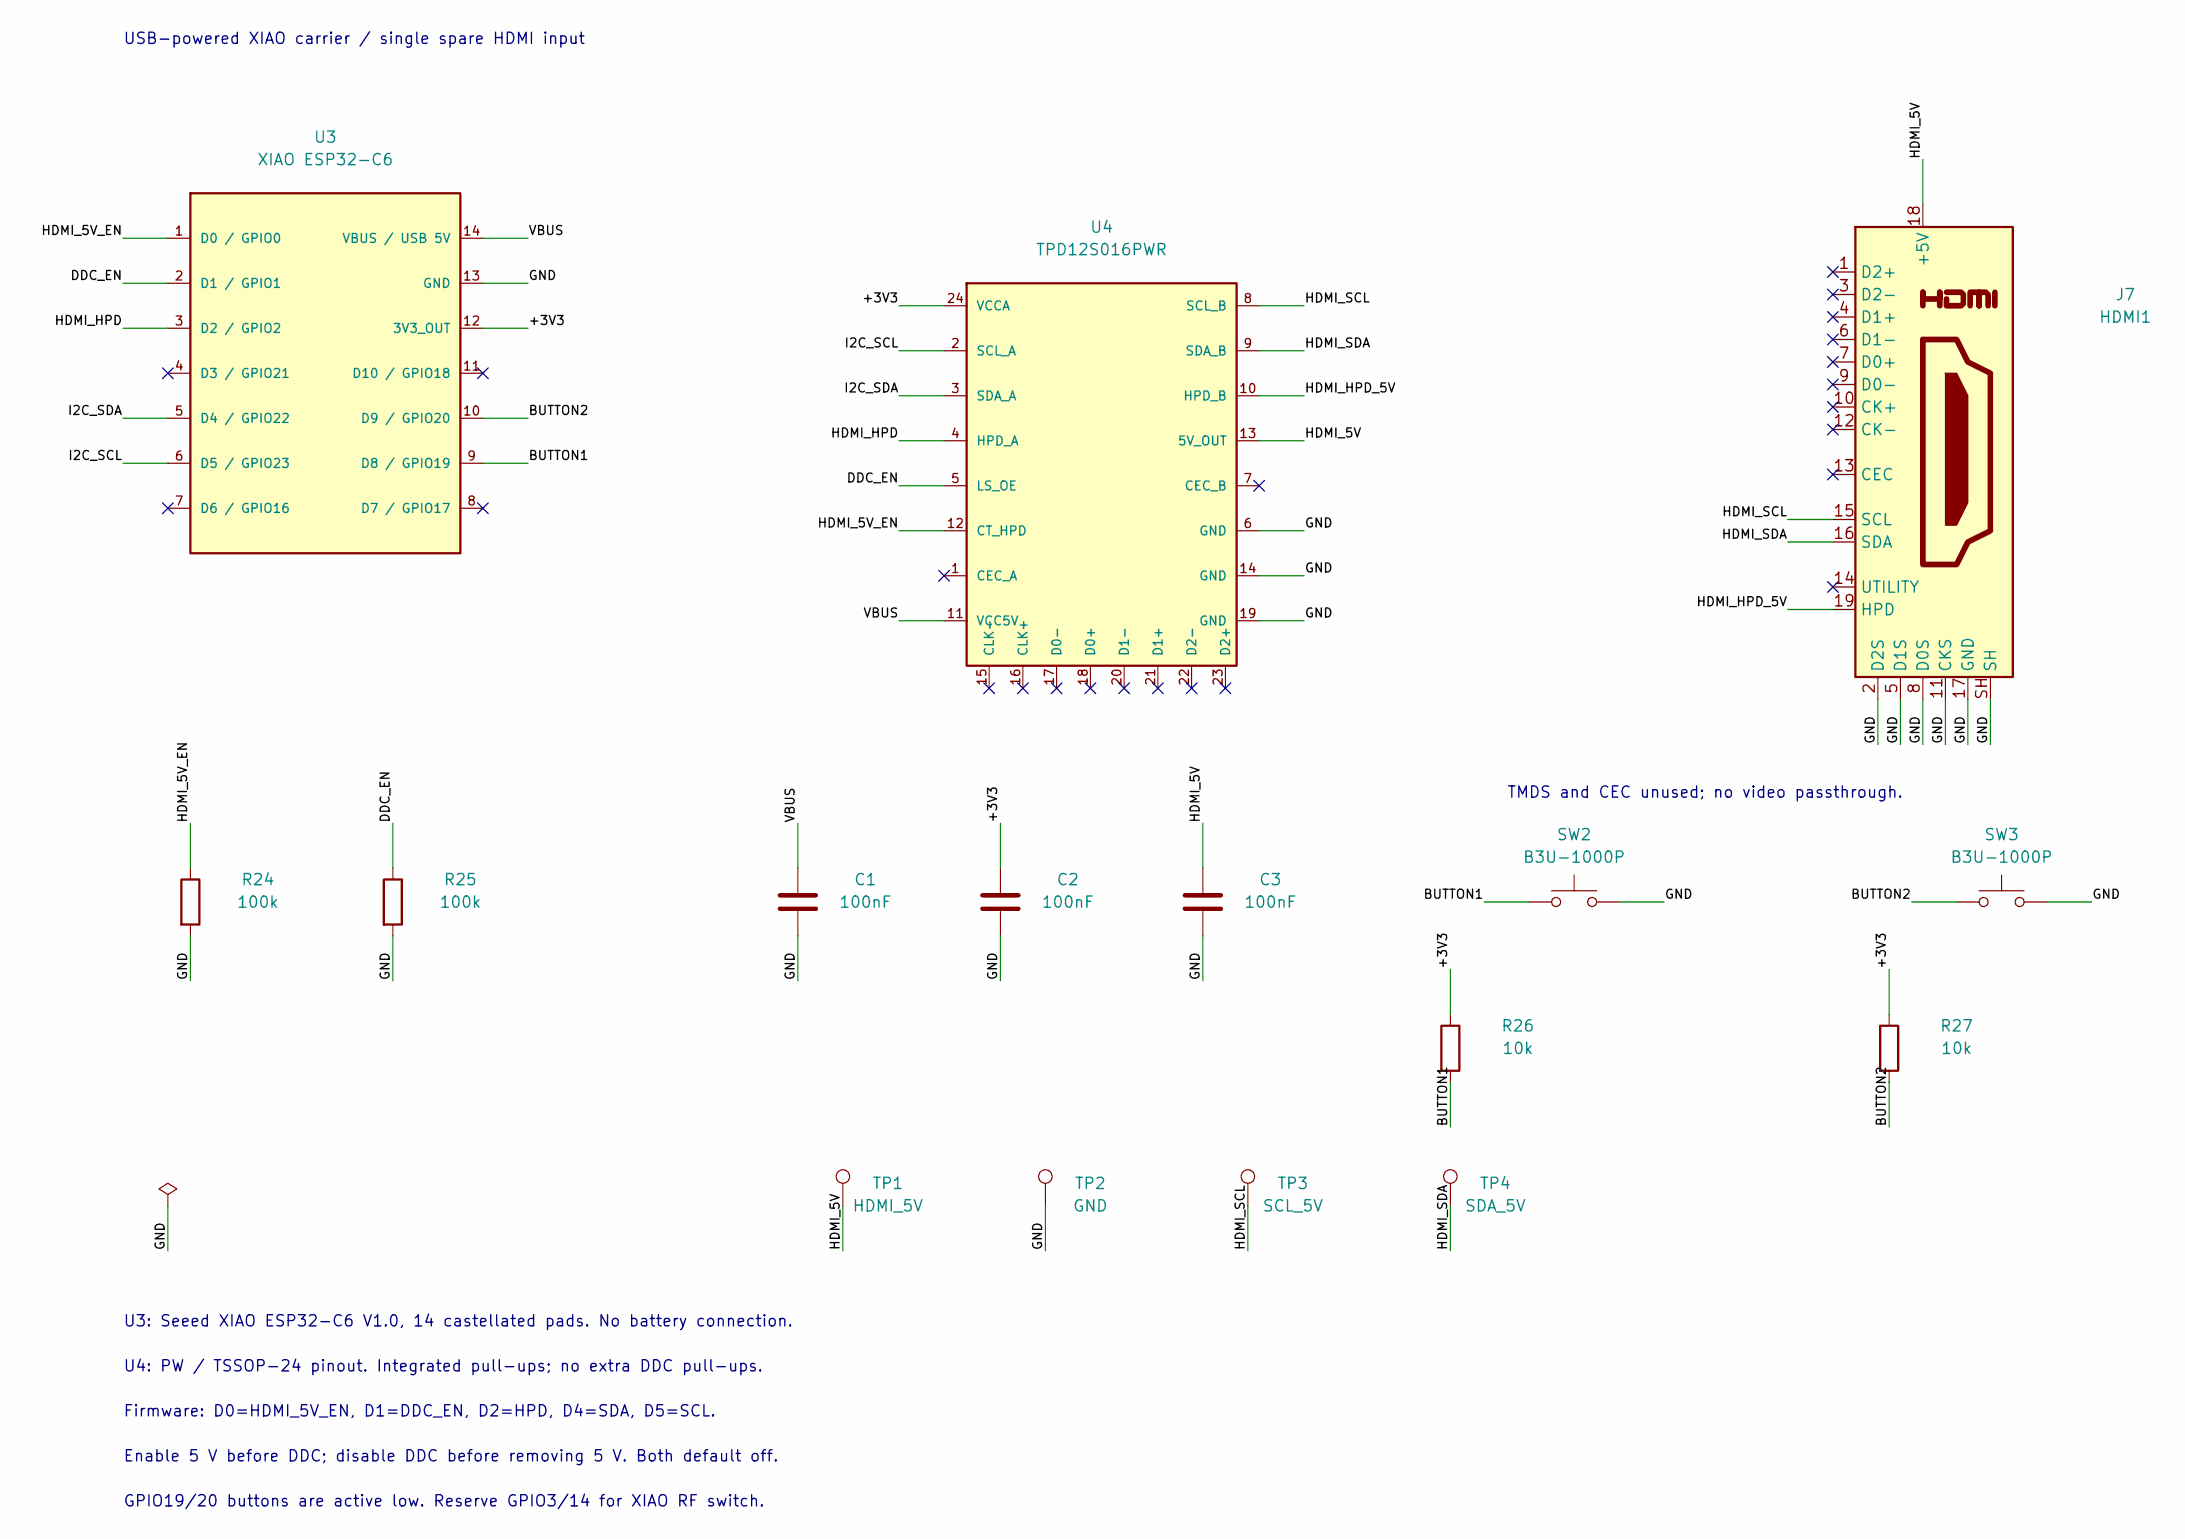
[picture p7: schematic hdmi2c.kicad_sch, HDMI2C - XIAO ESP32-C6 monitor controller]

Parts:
C1, C2, C3: 100nF; C_0603_1608Metric; MPN CC0603KRX7R9BB104; LCSC Part # C14663
J7: HDMI1; WURTH_685119134923_HDMI; MPN 685119134923; LCSC Part # C2930961
R24, R25: 100k; R_0603_1608Metric; MPN FRH0603B1003TS; LCSC Part # C51048211
R26, R27: 10k; R_0603_1608Metric; MPN SC0603F1002F2BNRH; LCSC Part # C3152123
SW2, SW3: B3U-1000P; SW_SPST_B3U-1000P; MPN B3U-1000P; LCSC Part # C231329
TP1: HDMI_5V; TestPoint_Pad_D1.0mm
TP2: GND; TestPoint_Pad_D1.0mm
TP3: SCL_5V; TestPoint_Pad_D1.0mm
TP4: SDA_5V; TestPoint_Pad_D1.0mm
U3: XIAO ESP32-C6; XIAO_ESP32C6_Castellated; MPN 113991254; LCSC Part # C27675191
U4: TPD12S016PWR; TSSOP-24_4.4x7.8mm_P0.65mm; MPN TPD12S016PWR; LCSC Part # C201665

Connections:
/+3V3: C2.1, R26.1, R27.1, U3.12 (3V3_OUT), U4.24 (VCCA)
/BUTTON1: R26.2, SW2.1, U3.9 (D8_/_GPIO19)
/BUTTON2: R27.2, SW3.1, U3.10 (D9_/_GPIO20)
/DDC_EN: R25.1, U3.2 (D1_/_GPIO1), U4.5 (LS_OE)
/GND: C1.2, C2.2, C3.2, J7.2 (D2S), J7.5 (D1S), J7.8 (D0S), J7.11 (CKS), J7.17 (GND), J7.SH, R24.2, R25.2, SW2.2, SW3.2, TP2.1 (1_1), U3.13 (GND), U4.6 (GND), U4.14 (GND), U4.19 (GND)
/HDMI_5V: C3.1, J7.18 (+5V), TP1.1 (1_1), U4.13 (5V_OUT)
/HDMI_5V_EN: R24.1, U3.1 (D0_/_GPIO0), U4.12 (CT_HPD)
/HDMI_HPD: U3.3 (D2_/_GPIO2), U4.4 (HPD_A)
/HDMI_HPD_5V: J7.19 (HPD), U4.10 (HPD_B)
/HDMI_SCL: J7.15 (SCL), TP3.1 (1_1), U4.8 (SCL_B)
/HDMI_SDA: J7.16 (SDA), TP4.1 (1_1), U4.9 (SDA_B)
/I2C_SCL: U3.6 (D5_/_GPIO23), U4.2 (SCL_A)
/I2C_SDA: U3.5 (D4_/_GPIO22), U4.3 (SDA_A)
/VBUS: C1.1, U3.14 (VBUS_/_USB_5V), U4.11 (VCC5V)

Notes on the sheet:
USB-powered XIAO carrier / single spare HDMI input
U3: Seeed XIAO ESP32-C6 V1.0, 14 castellated pads. No battery connection.
U4: PW / TSSOP-24 pinout. Integrated pull-ups; no extra DDC pull-ups.
Firmware: D0=HDMI_5V_EN, D1=DDC_EN, D2=HPD, D4=SDA, D5=SCL.
Enable 5 V before DDC; disable DDC before removing 5 V. Both default off.
GPIO19/20 buttons are active low. Reserve GPIO3/14 for XIAO RF switch.
TMDS and CEC unused; no video passthrough.

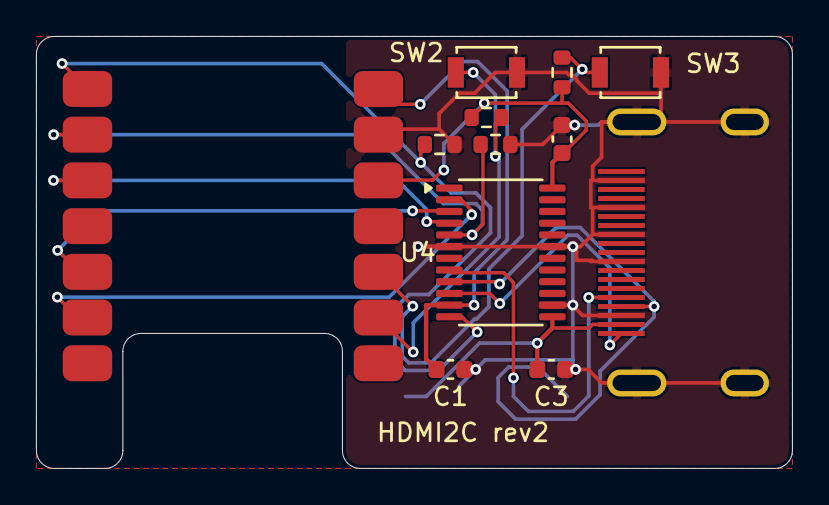
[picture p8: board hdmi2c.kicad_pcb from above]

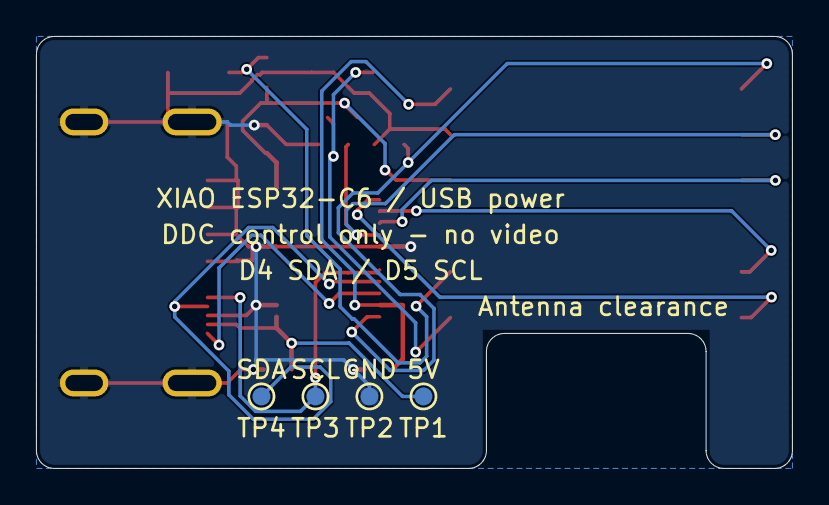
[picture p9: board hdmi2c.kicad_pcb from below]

Board: 2 copper layers, 42.0 x 24.0 mm, 16 parts (4 on the bottom side), 14 nets.

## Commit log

2026-09-12 Add project configuration files and initial scripts for HDMI2C development
    [hdmi2c.kicad_pcb, hdmi2c.kicad_sch]
2026-09-12 Add rev2 prototype files and update design parameters for HDMI2C carrier
    [bom.csv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]
2026-09-12 Add detailed 3D model for XIAO ESP32-C6 and update related files
    [Seeed_Studio_XIAO_ESP32C6.step, assembly.step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]
2026-09-12 Update creation dates and enhance BOM files for rev2 prototype
    [assembly.step, bom-design.csv, bom-jlcpcb-draft.csv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]
2026-09-13 Update creation dates and LCSC part number for J7 in BOM and related files
    [assembly.step, bom-design.csv, bom-jlcpcb-draft.csv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]
2026-09-13 Add JLCPCB draft CPL generation and update related documentation
    [cpl-jlcpcb-draft.csv]
